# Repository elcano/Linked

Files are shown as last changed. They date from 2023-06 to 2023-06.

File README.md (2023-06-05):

# Linked
Physical coupling of vehicles

We evision modular electric automated vehicles that weigh less than the riders. Such vehicles are supported by other code in the Elcano repository. The Linked repository contains CAD files for mechanical parts that allow vehicles to couple into a road train that behaves as a single vehicle. The Linked repository will also contain software to enable vehicles to dock and undock.
Automated vehicles travelling in platoons reduce energy consumption and increase road capacity. The effects are better with a smaller gap between vehicles. However, a small gap results in a jerky ride as the vehicle constantly adjusts its following distance. Our solution is to shrink the gap to zero and drive bumper-to-bumper. Students at University of Washington, Bothell have developed a prototype couple that allows two vehicles to join together or separate while moving. The mechanism includes a spring to eliminate jerks.

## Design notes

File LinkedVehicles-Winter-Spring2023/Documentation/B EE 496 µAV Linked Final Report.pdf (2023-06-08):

## Final Report

## µAV Linked Vehicles

## 2022-2023 Academic School Year

## Sponsor: Tyler Folsom

## Devin Taing

## Rebecca Sasten

## Fletcher Kurita

## Li-Ling Plume

### Table of Contents

### 1. Overview

Introduction

This document serves as a technical user manual intended to provide an outline of the device that has been designed to fulfill the requirements as provided by Micro-AV. This device is to serve as a coupling mechanism which automatically links stationary or non-stationary mini-vehicles such as electric tricycles or vehicles similar to the ELF vehicle. It is important to note that the vehicle for which the system will be adapted to has not been finalized, and so instead of finalizing a design for a mode mounting between the vehicle and the linking system, a standardized coupling is to be set instead. Figure 1 provides the general appearance of the entire assembly.

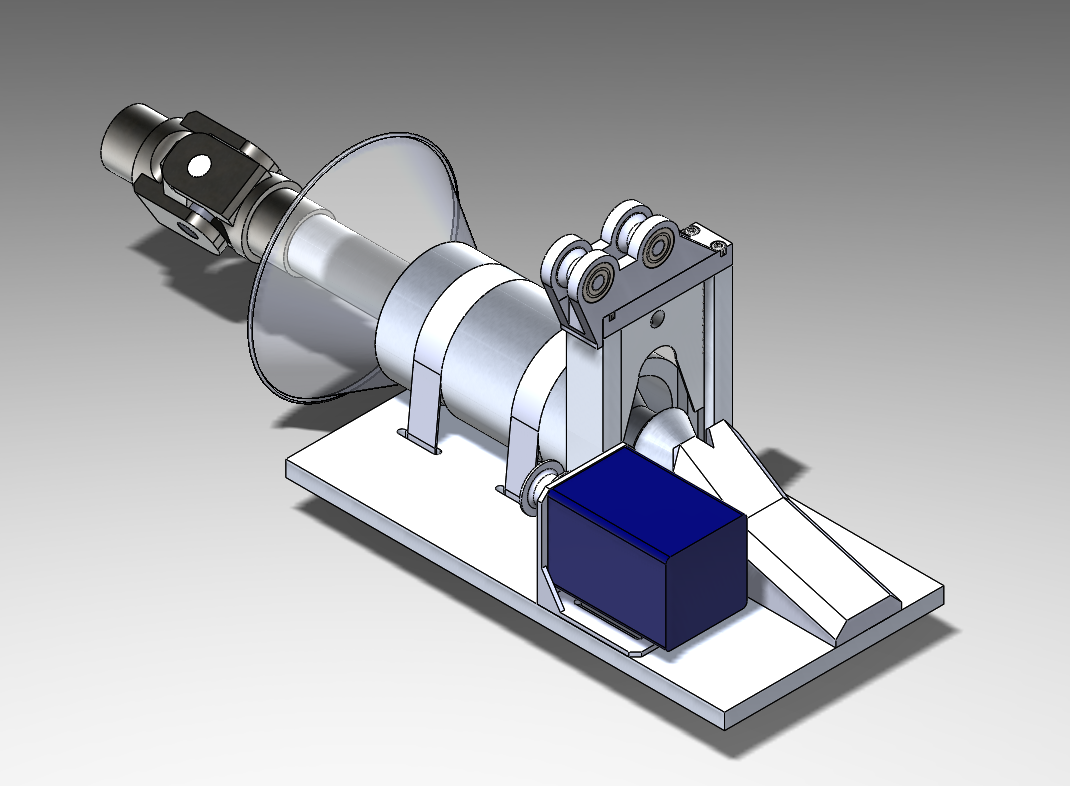
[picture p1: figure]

Figure 1. General Appearance of Assembly

Project Initial State

The system in its initial state was conceptual. The existing physical systems consisted of two separate trike systems that were not fully motorized with some electrical systems. As for the coupling system, due to the fact that the system was yet to be designed, there were no physical components or materials readily available on hand or to be ordered.

The project existed primarily as a set of requirements that needed to be fulfilled. The system was to be able to link two vehicles to one another by utilizing a bumper system without requiring direct human intervention when either coupling or decoupling. The system was to be mounted to be compatible with both ELF vehicles and electric trikes. Due to the fact that the trikes were already on hand, the system was to be designed according to the trikes. The requirements and constraints are to be further detailed below.

Constraints

The following system has been designed to meet the following specifications:

- Coupling is purely automatic
- Decoupling does not require human interaction
- All components within system are capable of withstanding forces due to collisions with a 5 mile per hour differential
- Supports vehicle weights of 40 lbs
*A lifetime of approximately 30,000 couples – untested

The processes in which these specifications have been designed to be tested for will be detailed in section 7.

Key Features and Functionality

There are four primary components that interact in the system, the male assembly, the female assembly, the locking mechanism assembly, and the dampening assembly.

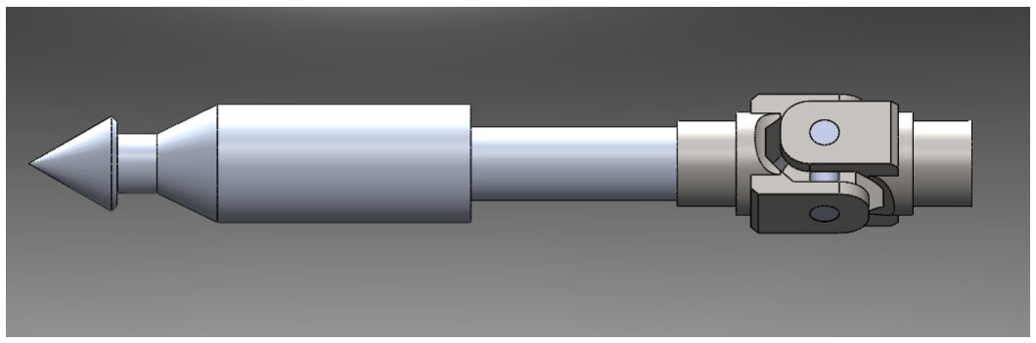
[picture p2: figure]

Figure 2. Male Assembly
The male assembly consists of a shaft which is connected to a universal joint. The end of the shaft is tapered to allow for a smoother coupling process when entering the female and locking mechanism assemblies. The universal joint allows for multiple degrees of freedom during the operation of the trike when it is coupled. The male assembly is to be mounted to the front of a vehicle.

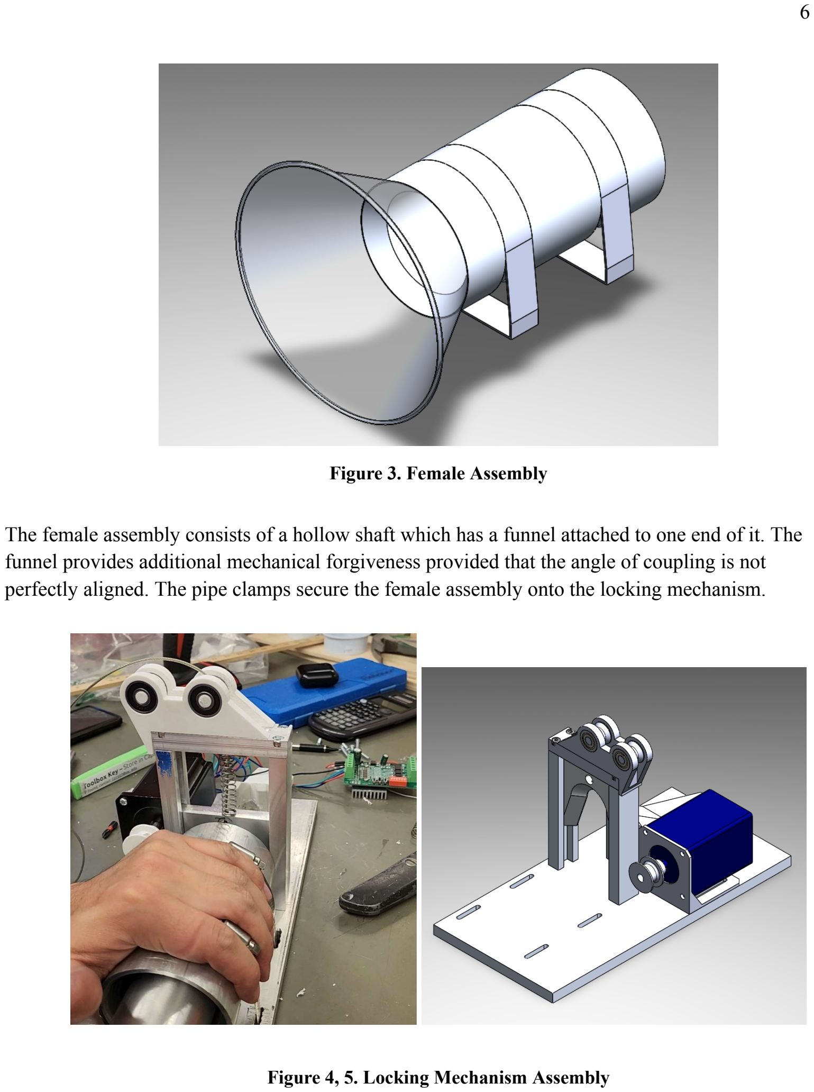
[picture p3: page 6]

Figure 3. Female Assembly

The female assembly consists of a hollow shaft which has a funnel attached to one end of it. The funnel provides additional mechanical forgiveness provided that the angle of coupling is not perfectly aligned. The pipe clamps secure the female assembly onto the locking mechanism.

Figure 4, 5. Locking Mechanism Assembly

The locking mechanism assembly consists of multiple mechanisms. The locking gate is the primary function that locks the male shaft into place after traveling through the female assembly. The face of the locking gate is chamfered such that it is concave facing the male assembly, allowing for it to be pushed easier. As the maximum diameter of the male head exceeds that of the gate, the male is automatically locked in once it passes through the gate. A rubber spring bumper will be mounted to the end of the base plate after the male shaft passes through the gate, which will prevent it from over-traveling.

To decouple, a stepper motor applies torque to a pulley and cable which pulls the locking gate up. Return springs apply a downward resistive force such that tension remains on the cable, preventing it from becoming unraveled, and pushes the locking gate down to resting position, where it is making contact with the base plate.

### 2. Parts List

### TOP LEVEL

ITEM NO | DESCRIPTION
1.0 | MALE ASSEMBLY
2.0 | FEMALE ASSEMBLY
3.0 | LOCKING MECHANISM ASSEMBLY
4.0 | DAMPING ASSEMBLY
5.0 | TEST ASSEMBLY

### 1. MALE ASSEMBLY

ITEM NO. | ITEM | DESCRIPTION
1.1 | MALE SHAFT | Universal Joint Assemblies (Standard Series): 1 1/4’’ x 1 1/4’’ I.D.(Inner Diameter), 1000 RPM, 800 Lbs, 5" Overall Length, 1/4’’ Keyway, 133020
1.2 | U-JOINT | Universal Joint Assemblies (Standard Series): 1 1/4’’ x 1 1/4’’ I.D.(Inner Diameter), 1000 RPM, 800 Lbs, 5" Overall Length, 1/4’’ Keyway, 133020
1.3 | MALE SHAFT SET SCREW | 3/8-16 x 1/2" Hex Head Screw Bolt, 10Pcs 18-8 (304) Stainless Steel, Fully Threaded, Plain Finish, by SG TZH

### 2. FEMALE ASSEMBLY

ITEM NO. | ITEM | DESCRIPTION
2.1 | FUNNEL | 24 FL oz Tin Funnel
2.2 | PIPE CLAMP | VIVOSUN Stainless Steel Air Ducting Clamps, 4/6/8/12 Inch Adjustable Hose Clamps with Worm Drive for Ducting, Heating, Cooling, Exhaust, and Ventilation (Pack of 2) (12 inch size)
2.3 | FEMALE SHAFT | Multipurpose 6061 Aluminum Round Tube, 3/8" Wall Thickness, 3" OD, 2ft length

### 3. LOCKING MECHANISM ASSEMBLY

ITEM NO. | ITEM | DESCRIPTION
3.1 | BASE PLATE | Multipurpose 6061 Aluminum, 7/16" Thick, 6" x 12"
3.2 | LOCKING GATE | Multipurpose 6061 Aluminum, 7/16" Thick, 6" x 12"
3.3 | RAIL GUIDE | Multipurpose 6061 Aluminum Sheets and Bars 1/2" Thick 1" Extruded 2ft Length
3.4 | RETURN SPRING | Corrosion-Resistant Precision Compression Springs 2" Long, 0.42" OD, 0.336" ID, 302 Stainless Steel
3.4* | RETURN SPRING (ALT) | Corrosion-Resistant Precision Compression Springs 2" Long, 0.42" OD, 0.31" ID, 302 Stainless Steel
3.5 | RUBBER SPRING ASSY | Ultra-High-Load Fastener-Mount Compression Spring, 1" Long
3.6 | ARDUINO UNO BOARD | Arduino Uno REV3

3.7 | MOTOR | STEPPERONLINE Nema 23 Stepper Motor 2.4Nm(339.79oz.in) 4.0A 8mm Shaft 57x57x82mm 4 Wires
3.8 | MOTOR MOUNT | weideer 2Pcs 57mm Stepper Motor Mounting Bracket Alloy Steel L-Shape Fixed Seat for NEMA23 Stepper Motor with Screws and Nuts K-029-57
3.9 | BRAIDED CABLE | 18-8 Stainless Steel Lanyard - Not for Lifting, Ball with Shank/Plain-End, 3/64" Rope Diameter, 24" Long, Nylon
3.10 | DRIVER BOARD | HiLetgo TB6560 3A CNC Router Single 1 Axis Controller Stepper Motor Driver Board
3.11 | PULLEY HOLDER | 3D PRINTED PLA PULLEY HOLDER
3.12 | PULLEY | 3D PRINTED PLA PULLEY
3.13 | SCREW | Zn-Plated Alloy Steel Socket Head Screw, 8-32 Thread, 3/4" Long

### 4. DAMPING ASSEMBLY

ITEM NO. | ITEM | DESCRIPTION
4.1 | AIR SHOCK | DNM Damping 3 System Mountain Bike Air Rear Shock Rebound/Lock Out/Air Pressure Adjustable AL 7005 Shark/AL 6061 Shock Body 165mm (6.5") x 35mm 190mm (7.48") x 50mm 200mm (7.87") x 55mm
4.2 | AIR SHOCK MOUNT | 3D PRINTED

### 5. TEST ASSEMBLY

ITEM NO. | ITEM | DESCRIPTION
5.1 | DOLLY | NA

Cost Estimate

ITEM NO. | ITEM | PRICE | QTY | NOTES | SOURCE
1.1 | MALE SHAFT | $ 45.64 | 1 | | Link (https://www.mcmaster.com/aluminum-shaft-stock/shape~rod-and-disc/diameter~2/appearance~matte/appearance~plain/material~aluminum/)
1.2 | U-JOINT | $ 66.70 | 1 | | Link (https://www.amazon.com/dp/B07DJ5LRYC?s=industrial&sp_csd=d2lkZ2V0TmFtZT1zcF9kZXRhaWw)
1.3 | MALE SHAFT SET SCREW | $ 8.13 | 1 | Purchased in Set of 10 | Link (https://www.amazon.com/Stainless-Threaded-Finish-SG-TZH/dp/B0B6BNVLQD?s=industrial)
2.1 | FUNNEL | $7.79 | 1 | | Link (https://www.mcmaster.com/products/funnels/metal-funnels-6/)
2.2 | PIPE CLAMP | $12.99 | 1 | | Link (https://www.amazon.com/STEELSOFT-Assortment-Stronger-Fasteners-Stainless/dp/B08Y6LSL3R)
2.3 | FEMALE SHAFT | $126.05 | 1 | | Link (https://www.mcmaster.com/products/shaft-stock/id~2-1-4/wall-thickness~3-4/wall-thickness~3-8/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)
3.1 | BASE PLATE | $31.17 | 1 | | Link (https://www.mcmaster.com/products/~/thickness~7-16/material~6061-aluminum/?s=aluminum+sheet+metal)
3.2 | BASEPLATE/LOCKING GATE | NA | 1 | Using same stock metal as Item 3.1 | Link (https://www.mcmaster.com/products/~/thickness~7-16/material~6061-aluminum/?s=aluminum+sheet+metal)
3.3 | RAIL GUIDE | $26.14 | 2 | | Link (https://www.mcmaster.com/products/bars/multipurpose-6061-aluminum-sheets-and-bars-7/width~1/thickness~1-2/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)
3.4 | RETURN SPRING | $7.33 | 1 | | Link (https://www.mcmaster.com/9002T434/)
3.4* | RETURN SPRING (ALT) | $8.14 | 1 | | Link (https://www.mcmaster.com/9002T438/)
3.5 | RUBBER SPRING | $11.43 | 1 | | Link (https://www.mcmaster.com/catalog/129/1505/9677K12)
3.6 | ARDUINO UNO BOARD | $29.95 | 1 | | Link (https://www.amazon.com/Arduino-A000066-ARDUINO-UNO-R3/dp/B008GRTSV6)
3.7 | MOTOR | $25.99 | 1 | | Link (https://www.amazon.com/STEPPERONLINE-Stepper-Motor-339-79oz-57x57x82mm/dp/B091C37FJ2?hvadid=532798192203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)
3.8 | MOTOR MOUNT | $10.99 | 1 | | Link (https://www.amazon.com/dp/B09374HZHF?s=hi&sp_csd=d2lkZ2V0TmFtZT1zcF9kZXRhaWxfdGhlbWF0aWM)
3.9 | BRAIDED CABLE | $3.07 | 1 | | Link (https://www.mcmaster.com/products/braided-wire/attachment-type~plain/length~24/flexibility~flexible/diameter~3-64/)
3.10 | DRIVER BOARD | $11.39 | 1 | | Link (https://www.amazon.com/HiLetgo-TB6560-Router-Controller-Stepper/dp/B00LPK02SY)
3.11 | PULLEY HOLDER | NA | NA | 3D PRINTED | NA
3.12 | PULLEY | NA | NA | 3D PRINTED | NA
3.13 | SCREWS | 8.03 | 1 | Purchased in Pack of 50 | Link (https://www.mcmaster.com/catalog/129/3498/90128A197)
4.1 | AIR SHOCK | $119.98 | 1 | | Link (https://www.amazon.com/DNM-Damping-Mountain-Pressure-Adjustable/dp/B00FLTZ2ZS/)
4.2 | AIR SHOCK MOUNT | NA | 1 | | Link (https://www.amazon.com/motorcycle-absorption-suspension-mounting-Eliminator/dp/B09WF424ZL)
| COST OF PARTS | $ 552.88
| COST OF MACHINING | $ 326.87
| TOTAL COST | $ 879.75

### 3. Machining Drawings and Documentation

Male Shaft

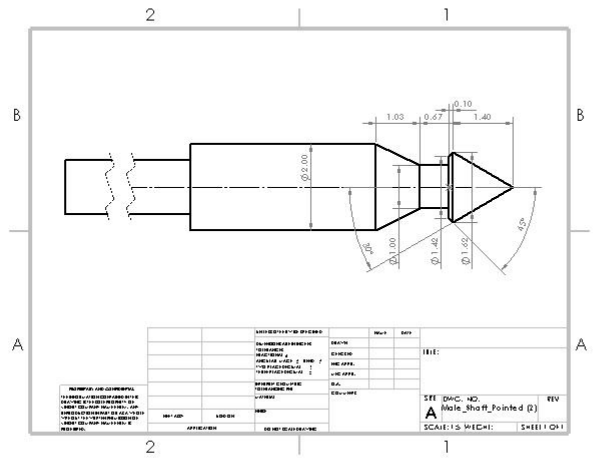
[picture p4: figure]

Figure 6. Male Shaft Machining Schematic

The male shaft was arguably the most complex machined item made in the entire assembly. The male shaft was made from Item No. 1.1. Item No. 1.1 was cut down the middle on the vertical band saw to create 2 roughly 12” long pieces. Each 12” piece of stock was loaded into the lathe with the 4 jaw independent chuck in addition to the live center mounted in the tail stock in order to ensure adequate contact before machining on the lathe. The first step of machining the male shaft was to cut the taper on the tip of the male shaft. This was done by setting the compound slide to the required angle and utilizing the left handed turning tool. After the taper was completed the interior shoulder and taper towards the base of the shaft were cut simultaneously with the same left handed turning tool. The dial gauge was utilized for this application to ensure accurate dimensions. The chamfer on the tip of the male shaft was completed also with the compound slide. A shoulder was turned down on the end of the shaft to fit into the universal joint. For weight savings the center of the shaft was core drilled with a large diameter drill bit roughly 5-6” into the shaft. If a longer drill bit was available, the shaft would have been drilled further to reduce weight even more. Weight can also be reduced in the future by bringing the interior diameter (fitting the universal joint) further up the shaft therefore extending that shoulder to reduce even more material.

Female Shaft

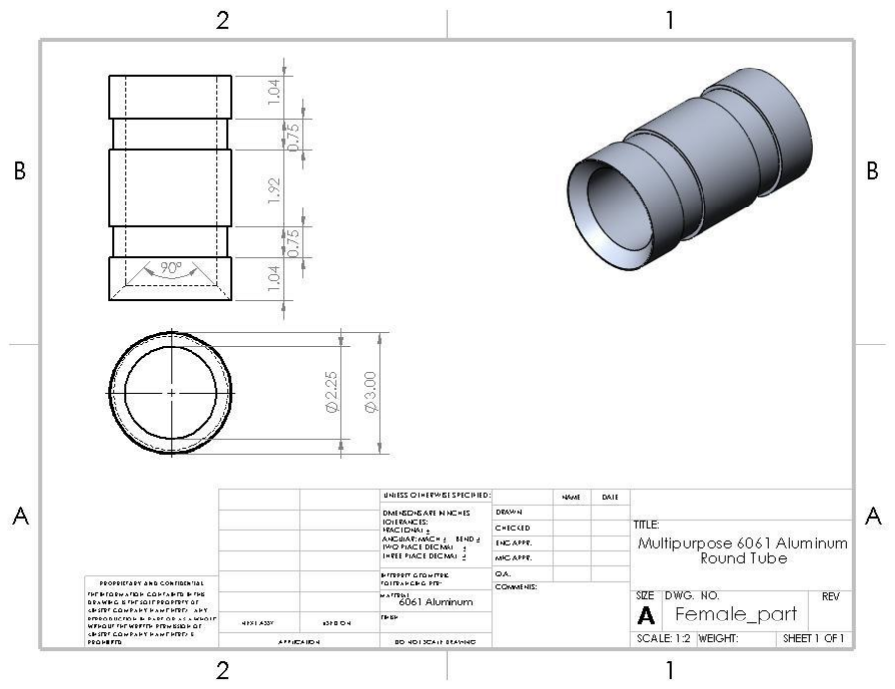
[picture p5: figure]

Figure 7. Female Shaft Machining Schematic

Female shaft was made from Item No. 2.3. Two (roughly) 5.5” lengths were cut from each end of the bar stock on the vertical bandsaw. After each length was cut to size the interior 45 degree chamfer was done with a right hand turning tool on the lathe. The two indented bands for the pipe clamps were also done with a right hand turning tool and pre-planned and measured according to the drawing above. These bands were not made exactly to spec as they can be within a very rough tolerance for our application. To reduce weight in the future the female shaft could be shorter and made from aluminum stock with thinner walls that will still accommodate the forces of the system.

Rails

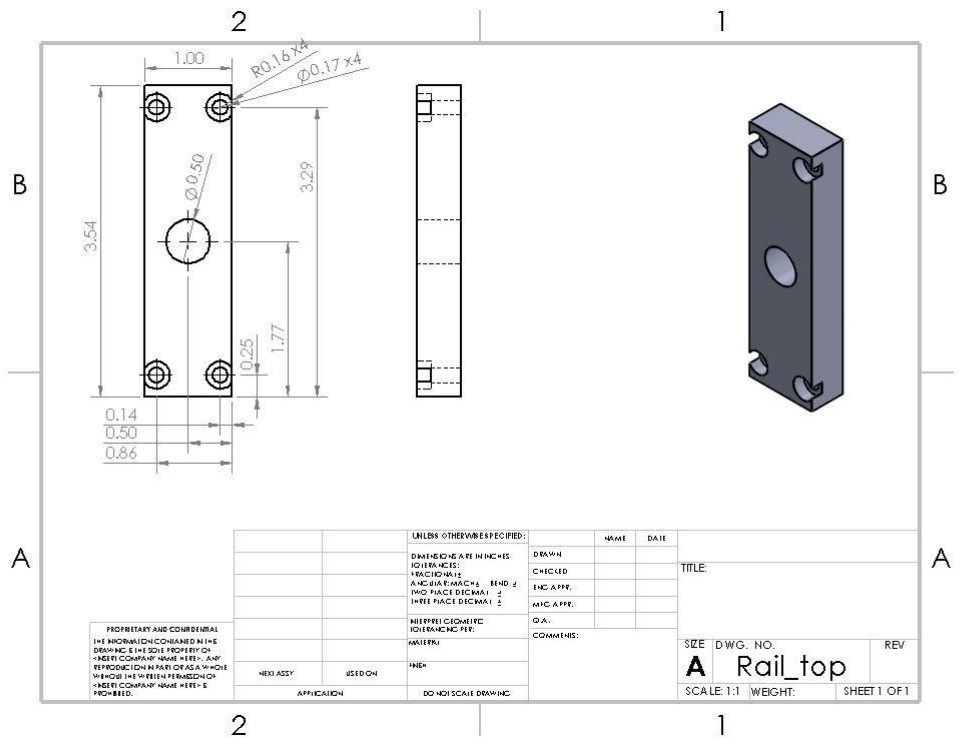
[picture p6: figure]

Figure 8. Rail Top Machining Schematic

The top portion of the rail was made of Item No. 3.3. The rail was cut to (roughly) 3.29” on the vertical band saw. After the rail was cut to size it was then scribed and center punched according to the dimensions listed above. The 5 holes were then center drilled and each hole was drilled to size as specified above. The 4 corner holes were counterbored with a larger drill bit size as the UWB shop does not have any counterboring bits.

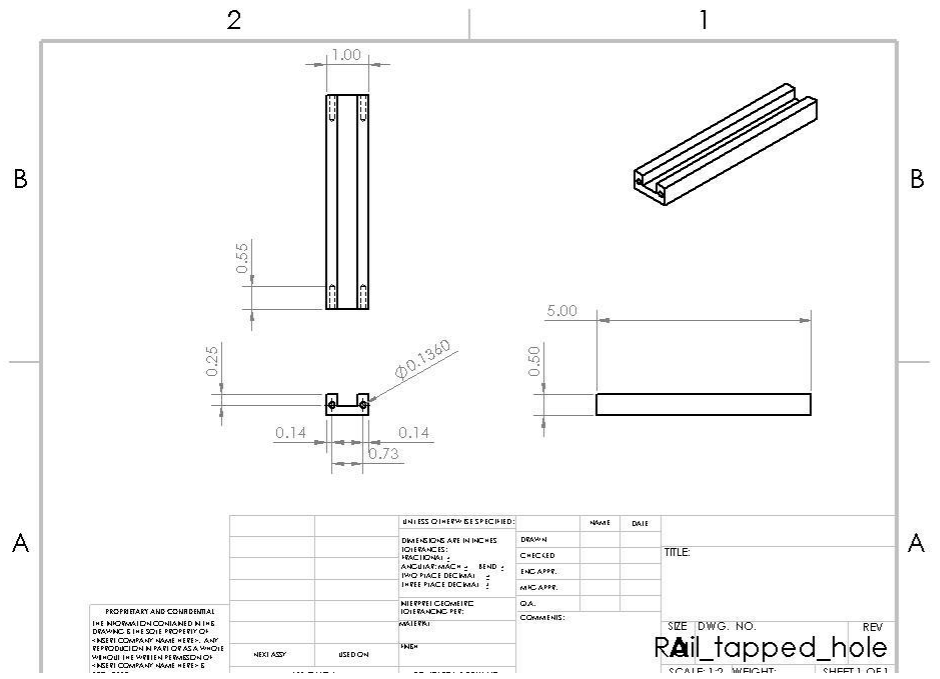
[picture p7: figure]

Figure 9. Rail Side Machining Schematic

The two side components of the rail are also made from Item No. 3.3. Two 5” pieces were cut from the stock with the vertical bandsaw with a rough 0.20” overhang to account for facing on the Manual Mill. After the pieces were cut roughly to size all 6 sides were then faced on the Manual Mill to ensure a smooth surface. After the pieces were faced they were individually channeled to create the interior channel to accommodate the locking gate. A ⅜” milling bit was used in accordance with the manual feed to take off roughly 20 thou of material at a time and create the channel. Once the channel was created it was then extended by a specified amount on each side of the pre-existing channel to create a total channel width of roughly half an inch.

Baseplate

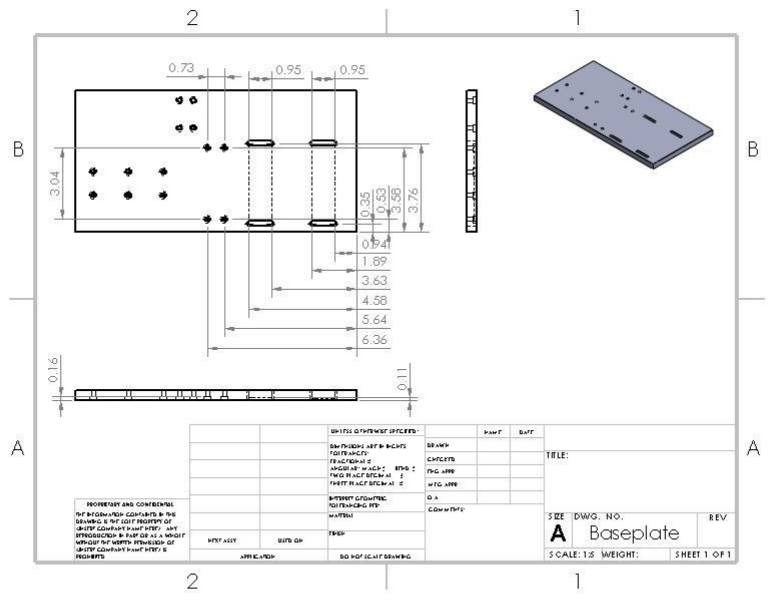
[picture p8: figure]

Figure 10. Base Plate Machining Schematic

The baseplate was made from Item No. 3.2. Two of the 7/16” edges were faced in order to create a perpendicular angle in order to accurately pre plan and dimension the holes on the base plate. All holes were center drilled and then drilled to size with the corresponding drill bit on the drill press. Some holes were counterbored with a larger drill bit size according to the drawing above. The slots for the pipe clamps were drilled out with a smaller drill bit and then were smoothed out with the use of a Dremel. In the future the baseplate can be modified to accommodate greater weight savings by cutting out parts of the plate not utilized by other components in the assembly. There will also be additional holes drilled into the baseplate in order to mount the assembly for testing.

Locking Gate

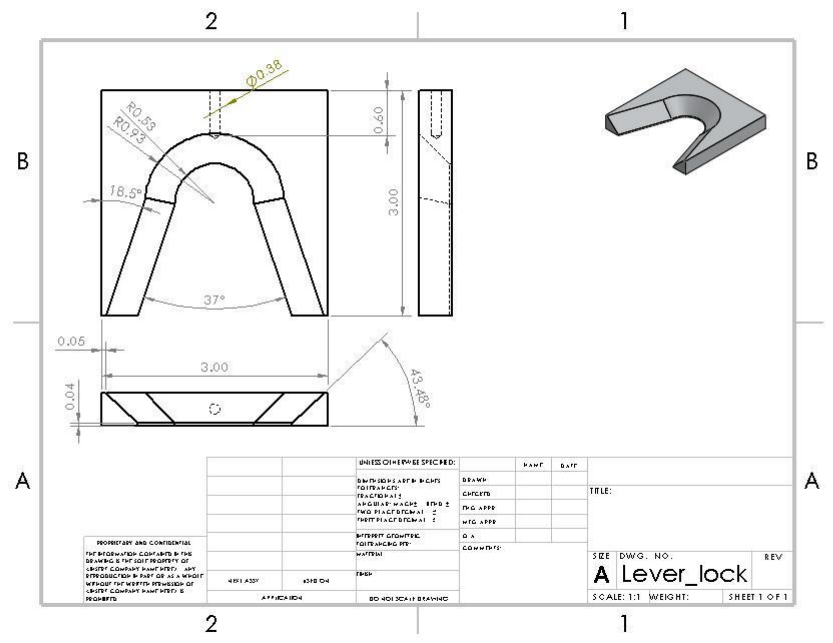
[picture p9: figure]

Figure 11. Locking Gate Machining Schematic

The locking gate was made from Item No. 3.2 and was cut to a 3.5”x3.5” square on the vertical band saw to allow room for cutting down to true size. This part needed to be within a tighter tolerance than the other machined piece such as the male and female shaft in order to properly interact with the machined rails. After the piece was cut to the 3.5” square, it was faced on all 6 sides on the manual mill and then loaded into the (Tormach 3 Axis) CNC. The CNC was utilized first to cut down the piece to an exact 3” square. Once the locking gate was cut to true size it was then loaded into the CNC again to have the interior portion removed according to the drawing above. This process was a bit of a trial and error as the G-CODE necessary for cutting the part had a few problems. The G-CODE was extracted through SolidWorks CAM after initializing the system according to the CNC specifications and toolcrib.

Additional Items

All additional items in the assembly were either 3D printed in house or purchased as is.

3D Printed:
- Pulley
- Dampening block
- Bearing Rail Mount for Cable Purchased:
- Universal Joint
- Universal Adjustable Pipe Clamps
- Stepper Motor
- Stepper Motor Mount
- Funnel

*The funnel was purchased and modified to fit the assembly. Modified and cut to size with metal shears.

Machining Time and Feasibility

Overall the machining of all components took roughly 30-40 work hours split between two people. There were many hardships associated with machining this project as the UWB machine shop was constantly in use and it was difficult to utilize the machines needed. There were also a limited number of hours available for shop use due to the requirement of supervision while running machinery.

If this project were to be outsourced to a machine shop it would take no more than half the time as a rough estimate. Outsourcing machining can cost anywhere between $40-150 per hour depending on the shop and what machines need to be utilized. This cost is not including the raw cost of the (stock) material itself which is roughly $300. On average I would estimate that outsourcing a second set to a machine shop to manufacture would be about $1500.

### 4. Electrical Schematics

Motor Wiring

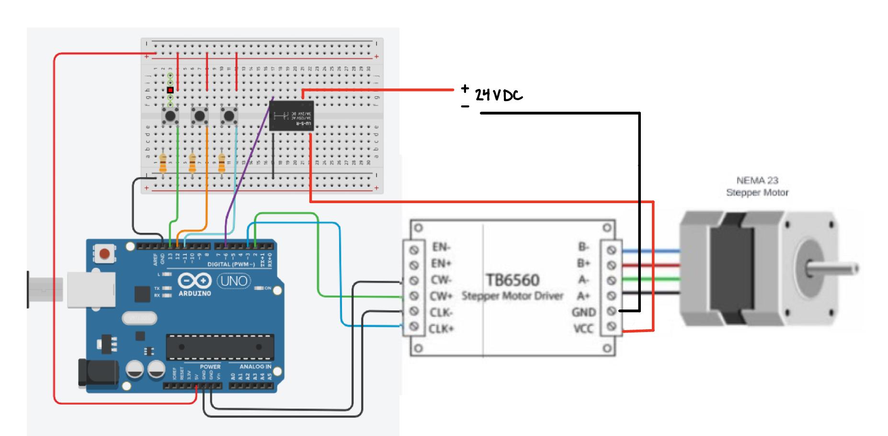
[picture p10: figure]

Figure 12. Motor Wiring Diagram

The CW+ connection of the motor driver is connected to pin 2 on the Arduino, which controls the direction of the motor. The CLK+ connection of the motor driver is connection to pin 3 on the Arduino, which controls the stepping. Additionally, there are three buttons, connected to pin 13, 12, and 11 of the Arduino through the breadboard. The button connected to pin 13 will cause the motor to raise the gate to decoupling height. The button connected to pin 12 will switch the relay and therefore cut power to the motor, dropping the gate. The button connected to pin 11 will single step the motor in the upward directions. The GND and VCC connections are to a 24V DC power supply through a relay controlled by the 5V signal from pin 6 on the Arduino.

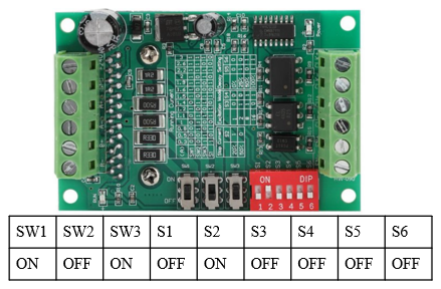
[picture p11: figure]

Figure 13. Motor Driver Switch Settings

The TB6560 is an analog motor driver board, which allows for control over the speed and stepping of the motor without making modifications to the code.. The interface for changing these parameters are the series of 9 switches on the bottom right corner of the board, as pictured above. The settings are shown in the figure above, and the switch configuration tables can be found in the Appendix section.

5

C

o

d

e

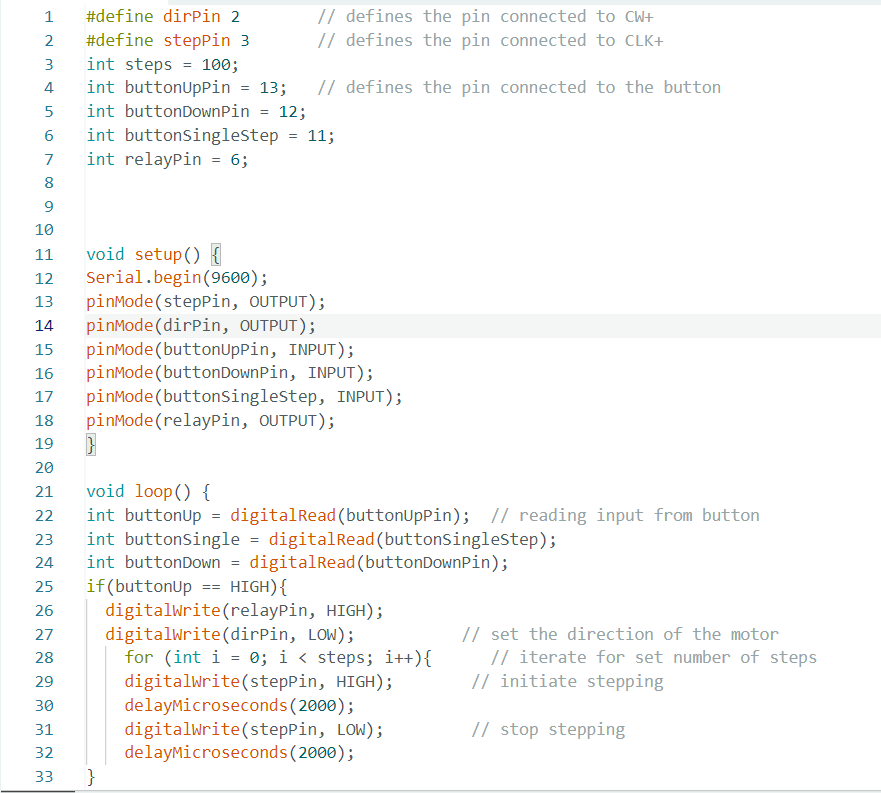
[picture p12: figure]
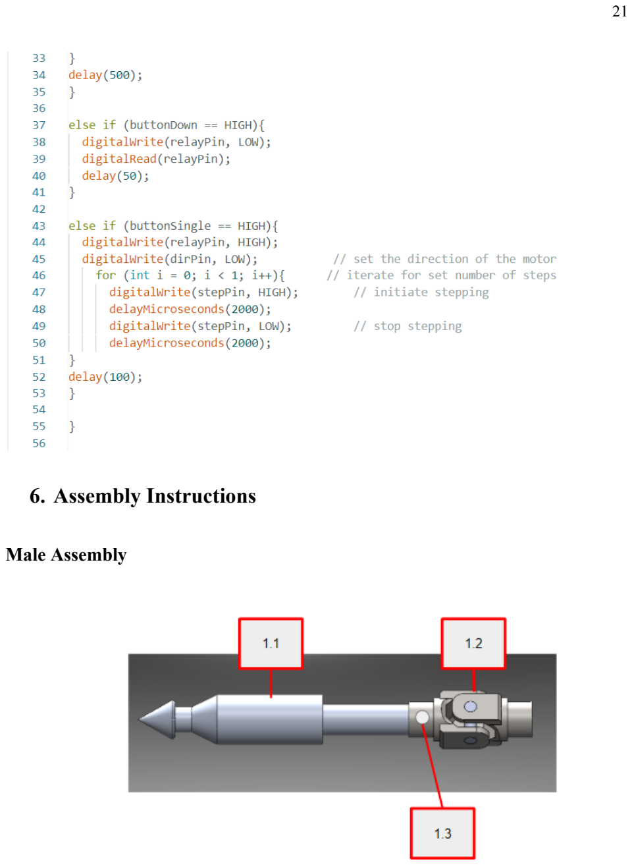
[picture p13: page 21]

### 6. Assembly Instructions

Male Assembly

Figure 14. Male Assembly
1. Using Item 1.3 (Male Shaft Set Screw), fix Item 1.2 (Universal Joint) onto Item 1.1 (Male Shaft)

Female Assembly

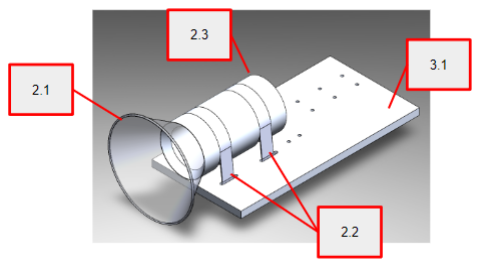
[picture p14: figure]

Figure 15. Female Assembly

1. Slide Item 2.1 (Funnel) over Item 2.3 (Female Shaft). Secure with metal zip ties.
2. Place the combined items 2.1 (Funnel) and 2.3 (Female Shaft) on Item 3.1 (Base Plate).
3. Route both counts of Item 2.2 (Pipe Clamp) through the four slots in Item 3.1 (Base Plate). Secure with screwdriver.

Damping Assembly

1. Construct Item 3.3 (Rail Guide), screwing them onto Item 3.1 (Base Plate) into the tapped holes as shown below using Item 3.13 (Screws).

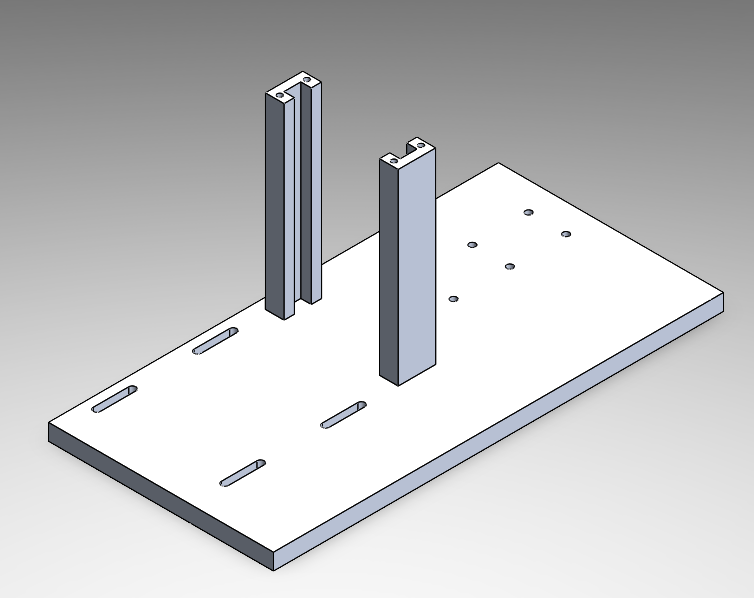
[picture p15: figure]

2. Place Item 3.2 (Locking Gate) into rails created by Item 3.3 (Rail Guide).

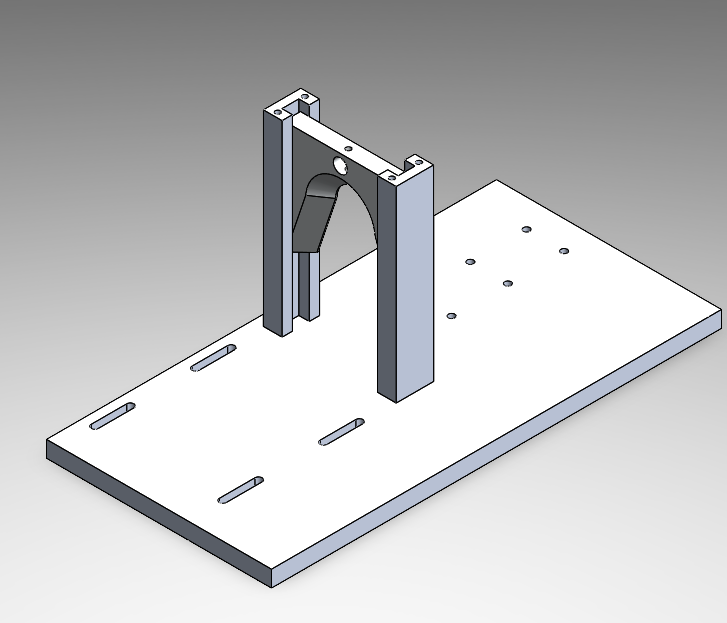
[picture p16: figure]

3. Route Item 3.9 (Braided Cable) through the slot in Item 3.2 (Locking Gate), then through Item 3.4 (Return Spring).
4. Install the top bar of Item 3.3 (Rail Guide) on top of the first two rail support structures. Screw in to secure with Item 3.13 (Screws). Secure Item 3.11 (Pulley Holder) on top of the top bar.

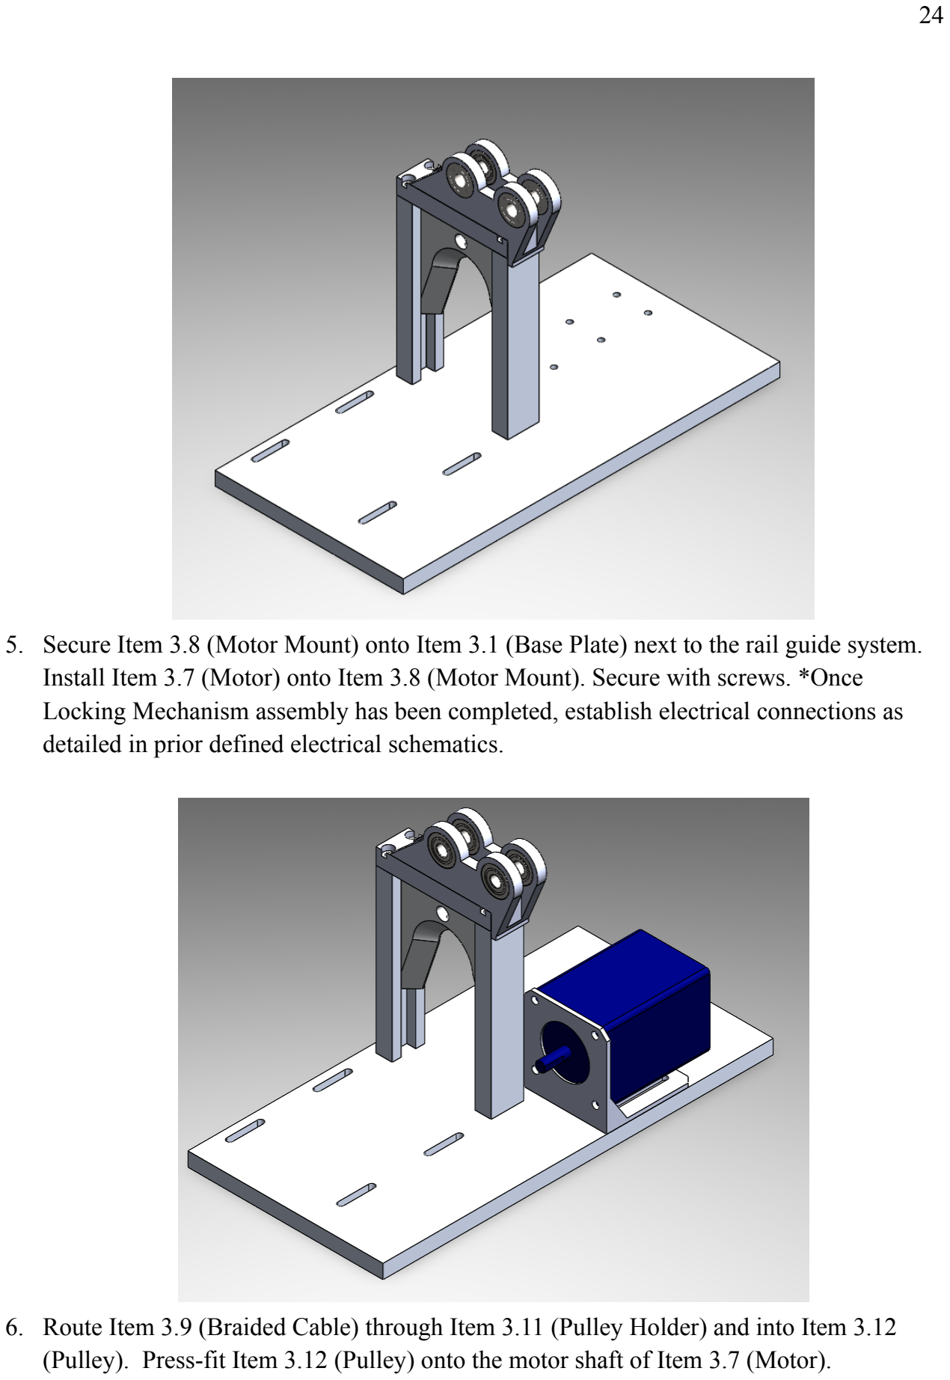
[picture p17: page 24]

5. Secure Item 3.8 (Motor Mount) onto Item 3.1 (Base Plate) next to the rail guide system. Install Item 3.7 (Motor) onto Item 3.8 (Motor Mount). Secure with screws. *Once Locking Mechanism assembly has been completed, establish electrical connections as detailed in prior defined electrical schematics.
6. Route Item 3.9 (Braided Cable) through Item 3.11 (Pulley Holder) and into Item 3.12 (Pulley). Press-fit Item 3.12 (Pulley) onto the motor shaft of Item 3.7 (Motor).

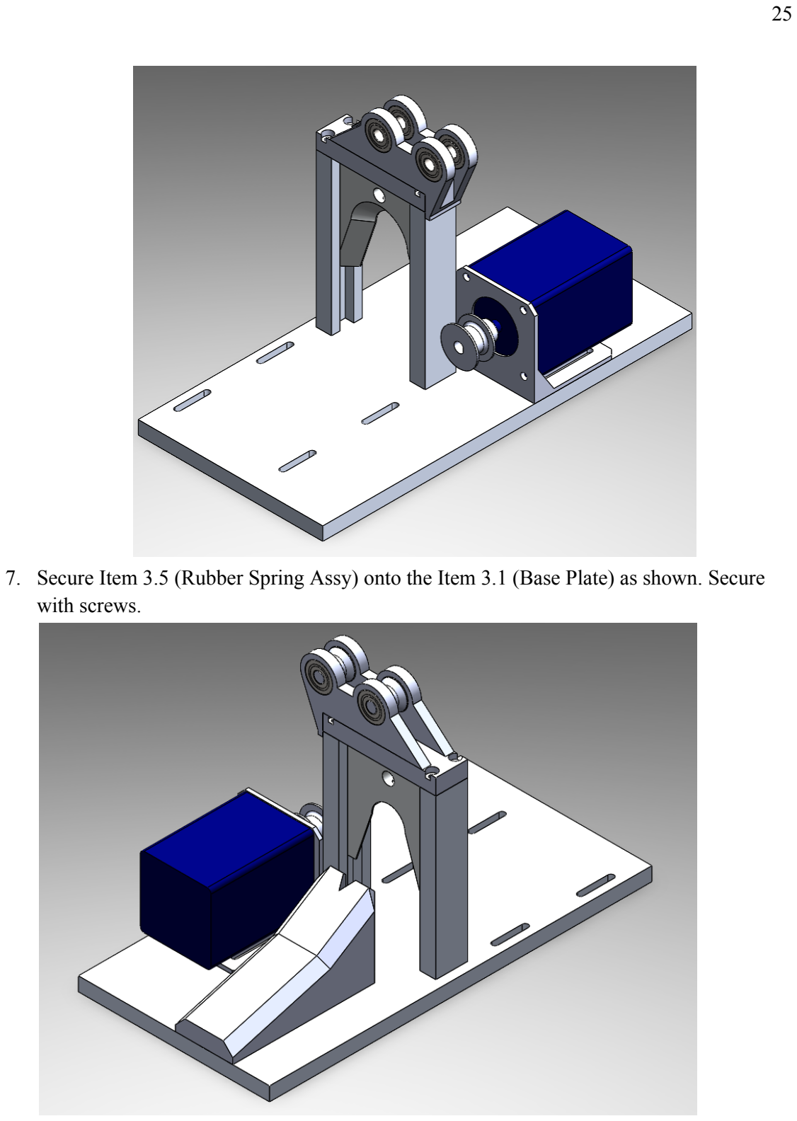
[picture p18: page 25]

7. Secure Item 3.5 (Rubber Spring Assy) onto the Item 3.1 (Base Plate) as shown. Secure with screws.

### 7. Testing & Verification

Procedures

In order to verify that the above design and process yields a system which meets specified requirements, a test procedure was drafted. There are three main functions which the system must satisfy, yielding three tests, which verify that
1. The system couples when the respective male and female assemblies collide at the specified speed differential (Coupling)
2. The system can allow for decoupling between male and female assemblies when programmed to do so (Decoupling)
3. The system allows for continuous linking between vehicles while traveling (Linking)

Test 1 – Coupling
1. Mount the respective male and female assemblies onto the test dollies. Allow a minimum of 10 feet between the dollies.
2. Leaving the dolly with the female assembly mounted stationary, push the dolly with the male assembly mounted towards the female assembly, aligning a path of collision.
3. Verify that the male shaft goes through the female assembly and pushes up the locking gate and passes through it, allowing the gate to close down on the shaft.

Test 2 – Decoupling
1. Mount the respective male and female assemblies onto the test dollies.
2. Couple the male and female assemblies by pushing the dollies towards each other.
3. Verify that power is being supplied to both the Arduino (5V) and the stepper motor (24V-36V).
4. Operate the switch button to verify that the motor
a. moves in the correct direction b. exerts the requisite torque to lift the locking gate while the system is coupled
c. exerts the requisite holding torque to maintain the gate at a height which allows the male shaft to decouple
d. releases the held torque to allow the locking gate to clamp down after a sufficient amount of time has elapsed.

Test 3 – Linking
1. Mount the respective male and female assemblies onto the test dollies.
2. Tie a rope around the dolly with the female assembly mounted.
3. Pull the dolly through various terrain conditions and verify that the coupler does not degrade in any fashion.

Test Reports

Since the tests performed were visual, there is no raw data and therefore a video is provided in the QR code below to show the current working state of the system. The video shows the coupling and decoupling test is demonstrated.

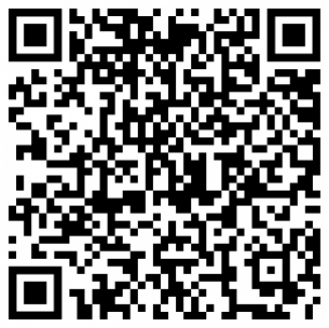
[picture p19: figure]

1. During coupling, the system performed as expected, with a reasonable amount of force required to lift the gate and secure the male shaft. This test was performed stationary and in alignment, as shown, and served to prove the success of the locking mechanism itself.
2. During decoupling, the motor was able to pull the gate up and hold it high enough for the male shaft to fully retreat and the return springs forced the gate back to the “ready” position. The test was deemed successful, however there may be room for improvement. A few observations during this test were that the springs were not strongly secured to the assembly relative to the amount of energy they stored, and the motor did not move smoothly or return to the exact same “ready” position each time. This caused some failed decoupling attempts, but these cases lessened as the motor code and assembly were tuned during the testing phase.

### 8. Future Work and Recommendations

To Be Completed:

I. Electrical Connection
A. Quick connect system near connection between male and female counterparts
B. All in one system (all on the same baseplate)
C. Acts as an interface for power and information to be shared between trikes

II. Integrated Shock/Dampening System
A. Male shaft machined in a way to make it “telescope” so dampening system can
| operate inside the shaft and be contained
B. Secondary/additional mounting for the dampening system in between the system
| and trikes consisting of an adjustable air shock to accommodate different weights/loads on the trikes
C. Upgrade the rubber hardstop (air shock, oil shock, spring)
1. Change the spring factor for coupling comfort based on
| cargo/passengers/etc.
D. Upgrade/improve the rubber hardstop’s mount to the baseboard
1. Make the position variable in the x,y,z
2. Upgrade material from PLA to more durable material that can sustain
| constant cyclic loading
III. | Mounting Currently the system is mounted to testing dollies for the sake of the current project scope. A concise mounting assembly will need to be manufactured and installed onto the trikes in order to incorporate the system into the Micro-AV physically linked vehicles.
| Both the male and female counterparts can be mounted to either the front or back of the trikes. It is important to note that mounting the male shaft to the front of the trike may pose some safety concerns. As a recommendation, It would also be easier to mount the female assembly to the back of the trikes given the current mounting surfaces, such as the rear bike rack frame. New mounting surfaces may also need to be manufactured for the trikes if the current mounting surfaces are not strong enough to accommodate the loads of the system. These mounting surfaces would need to be securely welded or bolted onto the chassis of the trikes. The mounting of the system will largely depend on further testing done once the trikes are fully operational.

IV. Improved Machining/Weight Reduction
A. Baseplate
1. Consider another material (wood or composites)
| *would recommend altering materials of other components before the baseplate due to it being the primary support structure and taking the majority of the load of the system*
2. Chamfer all edges for safety and usability
3. Improve design to reduce the overall unutilized sections
a) Run (SolidWorks) simulations to see where the baseplate is
| holding the most load/stress and shave the rest down
b) Trim with mill and bandsaw
4. Add small depressions/channels to the baseplate (utilizing the manual
| mill) that match up with the ribbed bands on the female part to keep it from sliding within the assembly
B. Rails
1. Run more testing for lifetime fatigue due to impacts because the rails take
| the majority of the impact and dynamic loading during coupling
2. If yielding or shear starts to develop increase the thickness to
| accommodate a third 8-32 screw or 2 larger screws
3. Make sure that both walls of the rail channel are down milled at a slow
| feed speed to get the smoothest finish (resulting in the lowest coefficient of friction)
C. Lever Lock
1. Run tests or simulations to find the best angle of the leverlock sweep
2. 7/16” flat aluminum stock is inexpensive, it is not difficult to manufacture
| multiple different iterations of the Lever Lock using the CNC machine
3. Potentially reduce the height of the lever lock to reduce the height of the
| rails (make the overall assembly shorter in the Z axis)
4. Change the lever lock material to one with a higher hardness (6061
| Aluminum is too soft for the male shaft to repeatedly hit long term, experience failure due to similar metals consistently colliding with another)
D. Top Connecting Rail
1. Reduce overall thickness (stresses are not high at the top of the rail
| assembly)
2. Clean up or redo the current one (done with minimal time and can be
| improved)
E. Female Shaft
1. Improve method of mounting to base plate (noted above)
2. Reduce thickness (and diameter) of tube stock for weight savings

3. Material change
F. Male Shaft
1. Reduce weight by coring the shaft or turn the outside of the shaft (from the second slope back) down to a smaller diameter and make a 3D printed sleeve that would save weight
2. Test different tip shapes for optimal coupling comfort
3. Test different tip shapes for optimal lever lock travel distance and engagement
4. Reduce overall length
G. Pulley System
1. Motor
a) Reduced motor size if friction and loads allow
b) Change to a geared setup for easier adjustments and increased engagement (complicated)
c) Print/manufacture housing to protect the current electronics and motor (motor and breadboard/wires exposed in current prototype)
d) Create a feedback loop to maintain set top and bottom positions
e) Remove the button press required to reset to the motor after decoupling (either have a sensor or a set time control)
2. Pulley
a) Manufacture out of metal to withstand long term stress (optional depending on further testing and results)
b) Change the radius if higher torque is required in the system
3. Pulley mount assembly
a) Reprint so skateboard bearings fit securely with a tighter tolerance
b) Reduce size (simulations needed for stresses to determine size)
c) Change material from PLA (PLA is not corrosion or weather resistant to long term exposure). Recommend Nylon X, PETG, or ABS.
4. Return springs
a) Attach to rails more securely
V. Second Set
A second set of both a male and female counterpart will need to be machined in order to allow for interchangeable coupling between two trikes. This second set will allow for each trike to have a corresponding set to be able to couple front to back and back to front. This is necessary for further implementation and testing of the physical platooning ideal that Micro-AV proposes for future use.
This second set can either be manufactured in house at UWB or it can be outsourced to a machine shop. Manufacturing in house would be more cost effective however it would be much more time consuming and results would not be up to par with those of outsourcing to a shop.

VI. Recommendations for Future Capstone Groups
As the current system and assembly is a rough prototype it would be beneficial for future groups to use this system as a starting point for future additions and improvements. As listed above, the system can be further modified through machining for weight reduction and increased efficiency. Given that the materials ordered to manufacture the system in house are inexpensive, it would be advantageous for future teams to experiment with creating their own male and female counterparts and the corresponding geometry. With continued prototyping the system will become increasingly more efficient.

One recommendation for future teams will be to further explore a solution that can accommodate yaw and pitch forces in the trikes when physically coupled. The current solution involves utilizing a universal joint connected to the male shaft to accommodate these forces. However, it is not feasible for use in transit as the universal joint does not have tight enough tolerances within the bearings and internal assembly to be able to support the weight of the male shaft when not connected to the rest of the system.

Overall, the main focus in future teams will revolve more heavily around the electrical side of the project as this year’s scope was focused mostly on the mechanical components. There will be mechanical changes that can be implemented and made as the electrical system and connections are further developed between the trikes and the assembly.

### 9. Appendix

References

[1] Shenzen Global Technology Co., LTD (Shenzen City, China). TB6560. Accessed: April 24, 2023. [Online]. Available: https://www.makerguides.com/wp-content/uploads/2019/08/TB6560-Manual.pdf
[2] “TB6560 Stepper Motor Driver with Arduino Tutorial.” MakerGuides. https://www.makerguides.com/tb6560-stepper-motor-driver-arduino-tutorial/ (retrieved April 24, 2023).

Additional Tables

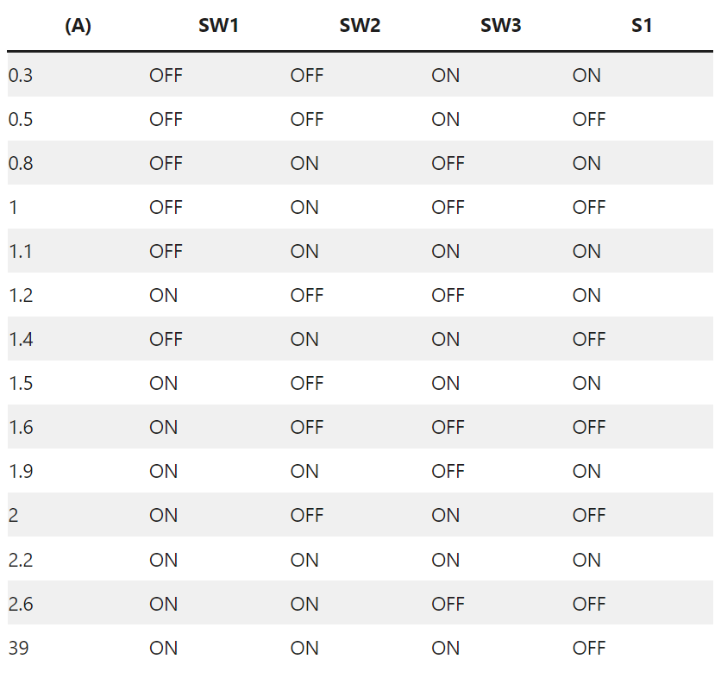
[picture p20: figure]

Figure A1. Current Table

The current going through the motor is adjusted by setting the switches SW1, SW2, SW3, and S1 on or off.

Figure A2. Stop Current Table

The stop current is the current used to hold the motor at a stopped position, and can be adjusted by turning S2 on or off. A higher stop current value will result in increased holding torque.

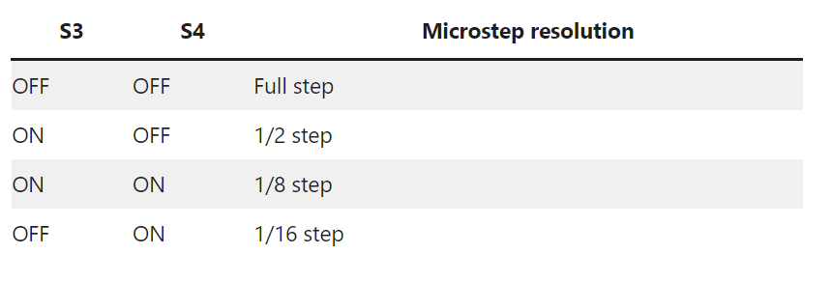
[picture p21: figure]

Figure A3. Microstep Table

The microstepping can be adjusted by turning switches S3 and S4 on or off. A smaller microstep resolution will result in smoother movement.

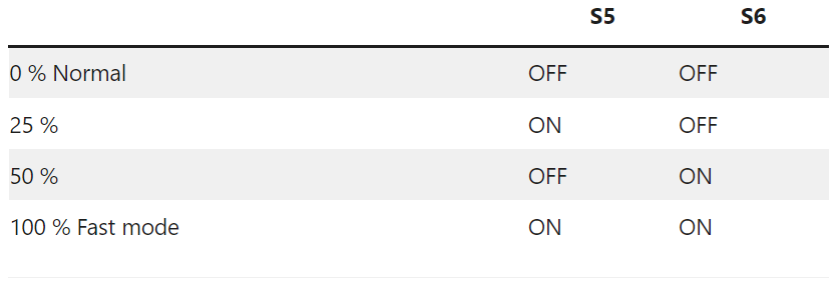
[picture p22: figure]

Figure A4. Decay Setting Table

The decay setting determines how the driver chip deals with back EMF from the motor, and can be adjusted using switches S5 and S6.

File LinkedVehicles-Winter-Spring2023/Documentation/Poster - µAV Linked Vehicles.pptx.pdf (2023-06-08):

# µAV - Linked Vehicles

# Devin Taing Li-Ling Plume Fletcher Kurita Rebecca Sasten

## BACKGROUND & INTRODUCTION

## dpt7@uw.edu lplume@uw.edu fletchku@uw.edu rsasten@uw.edu

## TEST METHODS & RESULTS

## CONCLUSION/FUTURE WORK

## KEY FEATURES

µAV is a company which aims to address vehicular inefficiencies in transportation. Emulating truck platooning to reduce fuel expenditure, µAV seeks to physically link small electric vehicles together instead. As these smaller vehicles can move independently, this proposes a modular bus system where vehicles can link and unlink as needed during transportation. To accomplish this, the design of a coupling system is required.

The system:
- is to couple automatically
- remains coupled until instructed otherwise
- does not require human intervention to decouple
- withstands collision forces with a 5 mph differential
- supports weights of 200 lbs
- approximately 30,000 couples

## REQUIREMENTS & CONSTRAINTS

Design an electromechanical system to allow coupling and uncoupling of small vehicles given requirements and constraints as defined below.

Potential Modular Bus Design OBJECTIVES

The designed and manufactured solution meets the expectations of the previously listed requirements and constraints.
Future work of the system includes:
- Mount system to trikes (photo of trike shown below)
- Electrical connection between male and female coupler for inter trike data transfer
- Mechanism to allow additional degrees of freedom
- Integrate additional shock dampening system for increased user comfort during coupling
- Machine second set of couplers
- Further weight reductions

Pulley System

Male shaft

Female part

Lever lock rails

Baseplate
Hardstop

Motor

Lever lock

Pulley system: Uses a 50 lb braided cable to lift the lever lock using the motor Lever lock: Specialized CNC part that locks the male shaft into place
Motor: Geared stepper motor to lift the lever lock during decoupling
Hardstop: Remaining momentum of the system is absorbed into the hardstop Baseplate: Main mounting surface for the system
Lever lock rails: Precision milled aluminum designed to hold the lever lock Female part: Aluminum tube stock designed to take the initial forces of coupling Male shaft: Precision turned aluminum that is the primary locking element
1 2

3

(1) Lever lock in the locked position ready for coupling
(2) Male shaft forces lever up
(3) Springs slam lever lock down to complete coupling
Uncoupling: Steps 3-1 aided by the stepper motor to lift the lever lock
SPONSOR: TYLER FOLSOM | SPECIAL THANKS TO: BILL ANDERSON, JACOB ROTH, JONG YOON

Images Courtesy of µAV

Scanning the QR code will lead to a short video demo. This video demonstrates that the system is able to:
a) couple automatically upon collision to two vehicles
b) disengage the locking mechanism and allow the vehicles to uncouple

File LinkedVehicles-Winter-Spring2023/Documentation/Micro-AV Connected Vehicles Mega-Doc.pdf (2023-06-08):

## Mechanical Engineering Capstone Project

## µ-AV Connected/Linked Vehicles

## Final Mega Document BME 494, 495, 496

## Rebecca Sasten, Devin Taing, Li-Ling Plume, Fletcher Kurita

## Advisor: Dr. Tyler Folsom

## Mentor: Dr. Jong Yoon

## Sponsor: Dr. Tyler Folsom

## University of Washington Bothell

µAV-Linked Page 2

Table of Contents
Table of Contents | 2
A. Design Strategy | 5
A.1.1 Design Strategy – User Insights and Research, Consumer Journey Map | 5
Empathy Map | 5
Customer Journey Map | 6
A.1.2 Design Strategy – User Insights and Research, Stakeholder Framing. | 8
Stakeholders Map/Matrix of Power | 8
A.1.3 Design Strategy – User Insights and Research, User Scenarios and Personas. | 9
A.1.4 Design Strategy – User Insights and Research, User Insight Report | 12

A.2.1. Design Strategy – Problem Understanding and Framing, Product Assumptions
Outline | 13
Partial Needs Statement 1 | 14
Partial Needs Statement 2 | 14
Partial Needs Statement 3 | 15
A.2.2. Design Strategy--Functionality (tasks and associated outcomes) | 16
A.2.3. Design Strategy--High-level Constraints on the Usability of the Product | 16
A.2.4. Design Strategy--Final Needs Statement and User Outcomes | 17
A.2.5. Design Strategy--Hypothesis Statement | 18
A.2.6 Design Strategy--Possible Inventions and Business Model | 18
Systems Level Sketch Invention 1 | 19
Platooning enabled by wireless information transfer which can be used to inform vehicles to control distance between one another. Utilizing WiFi or other forms of wireless communication between vehicles, signals containing information vital to road operation would be collected using proximity sensors, GPS, lidar, or other similar mechanisms. This information would be transmitted between all vehicles within a specific range, allowing their
driving to be informed and synchronized to the point of platooning. | 20
Systems Level Sketch Invention 2 | 20
Systems Level Sketch Invention 3 | 21
Lean Canvas | 22
A.2.6.1 Design Strategy--Final Invention | 22
A.2.7 Design Strategy – Product Planning Roadmap | 23
Product Roadmap | 24
Product Development Timeline | 25

B. Experience Design | 26
B.1 Experience Design – Human Interface Design, User Workflow | 26
User Experience Flow Diagram | 26
B.2 Experience Design – Human Interface Design, Environmental analysis | 27
B.3 Experience Design – Human Interface Design, Cultural factors mapping | 27

B.4 Experience Design – Human Interface Design, Information Architecture and Hierarchy 29

B.5 Experience Design – Human Interface Design, Analog Interface Design | 30
B.7 Experience Design – Human Interface Design, Best Use Practices Report | 31
System Maintenance Plan | 32

B.8 Experience Design – Human Interface Design, the Summary Document, in essence a
Usability Requirements Documentation. | 32
C. Requirement Documentation | 34
C.1.1 Design Decisions and Rationale | 34
Female Counterpart | 34
Male Counterpart | 35
C.1.2 Tier 1 Schematics (block diagram) | 36
Level 1 Roadmap of Major Elements | 36
C.1.3 Tier 2 Schematics for each element (block diagram) | 37
Level 2 Roadmap of Individual Pieces within Elements | 37
Shaft (male part) | 38
Universal Joint (male part) | 38
Spring/Damper (male part) | 38
Receiver (female part) | 39
Lever Locking Mechanism (female part) | 39
Electrical Connection | 40
C.1.4 Tier 3 Schematics (concrete connections between blocks) | 40
C.2 Estimation of cost of goods | 41
Cost of Goods Chart | 42
C.3 Schedule | 43
Technical GANTT Chart | 43
Documentation GANTT Chart | 44

Technical Tasks & Deadlines | 44
Documentation Tasks & Deadlines | 45
D. Concept Development [Demonstrating the solution] | 46
D.1 Concept Development – Technology mapping, risk analysis and feasibility plan | 46
Risk & Resources Component-Level Breakdown | 46
Feasibility Timeline | 49
D.2 Design Strategy – Technology mapping, Component Technology Research | 50

D.2.1 Concept Development, Concept Risk Identification & Mitigation - EE/Circuit Models 50
Locking Mechanism | 50

D2.2 Concept Development, Concept Risk Identification & Mitigation - Mechanical Models 51
Damper Test | 51

D.2.3 Concept Development, Concept Risk Identification & Mitigation - Firmware and Software
Models | 52

D.2.4 Concept Development, Concept Risk Identification & Mitigation - Human Interaction
Models | 52

D.2.5 Concept Development, Concept Risk Identification & Mitigation - System interface
modeling, testing and risk analysis | 52
References: | 54

A. Design Strategy
A.1.1 Design Strategy – User Insights and Research, Consumer Journey Map
Our direct customer is the company Micro-AV. We are tasked with developing a coupling system for two vehicles in order to show a proof of concept. With this proof of concept, Micro-AV will be closer to the goal of platooning multiple vehicles for various purposes. This long term goal of platooning vehicles has been described in depth below along with other potential considerations in order to show the importance of developing this product.

Empathy Map
| Customer 1 | Customer 2 | Customer 3
Description | Bike share companies (like Lime) | Delivery companies (like Amazon, Uber Eats, etc.) | Personal use
Job | Provide affordable and reliable transportation. | Provide efficient and affordable small deliveries. | Buy e-trikes directly from Micro-AV.
Pains | Initial cost of switching to autonomous e-trikes, maintenance. | Initial costs of adding autonomous e-trikes to the delivery fleet, maintenance. | Initial cost of buying the e-trike, small cargo space, maintenance.
Gains | Increased usage since e-trikes can redistribute themselves to high-demand locations, less energy cost with platooning of e-trikes, include customers who can’t ride bikes or scooters safely. | Energy cost savings of not operating large vehicles for small deliveries, less employees to pay, quicker turnaround times since modules can return for reloading before the entire route is complete. | Reduce individual carbon footprint, save money by not buying a large personal vehicle and paying for fuel/insurance, a convenient option for auto-drive.

Here, the Consumer Empathy Map outlines three types of customers who may use the Micro-AV Millipod. There are 3 types of customers (bike share companies, delivery companies, and personal use). The customers are people and companies who will be directly purchasing vehicles or services from Micro-AV, and their pains are primarily how their funds will be used, and the gains are how they will benefit from their purchase. Some of these customers, such as bike share companies and delivery companies will also have users that will pay to use these products. For example, the customers of the bike share company will be using the Millipod trikes to commute within the city, and the delivery company customers will be indirectly using the trikes to schedule their deliveries.

Customer Journey Map
The Customer Journey Map shows a potential process of a single customer deciding whether a Micro-AV Millipod is a worthwhile investment. This journey map follows a customer named Vlad, who is an analytical thinker and puts a lot of thought into his purchase decisions. His journey starts with seeing a couple ads for the Micro-AV Millipod trikes on multiple platforms. These commercials spark his interest, as he is looking for affordable, reliable, and accessible transportation through the city of Seattle, so he decides to explore the options of using a Micro-AV Millipod and compare the pros and cons with his needs. He spends considerable time exploring and comparing different options of using this mode of transportation, as well as doing cost analysis and reading customer reviews. After he is satisfied with the information he finds on the internet, he decides to test the vehicles for 2 weeks and take notes on his experience. Eventually he decides to purchase a Micro-AV Millipod trike directly from Micro-AV and use it as his every day mode of transportation throughout the city. He is satisfied with his purchase which leads him to recommend Micro-AV to his friends and family, and write a positive review on the Micro-AV website.

The Customer Journey Map is only meant to be a representation of a single future potential

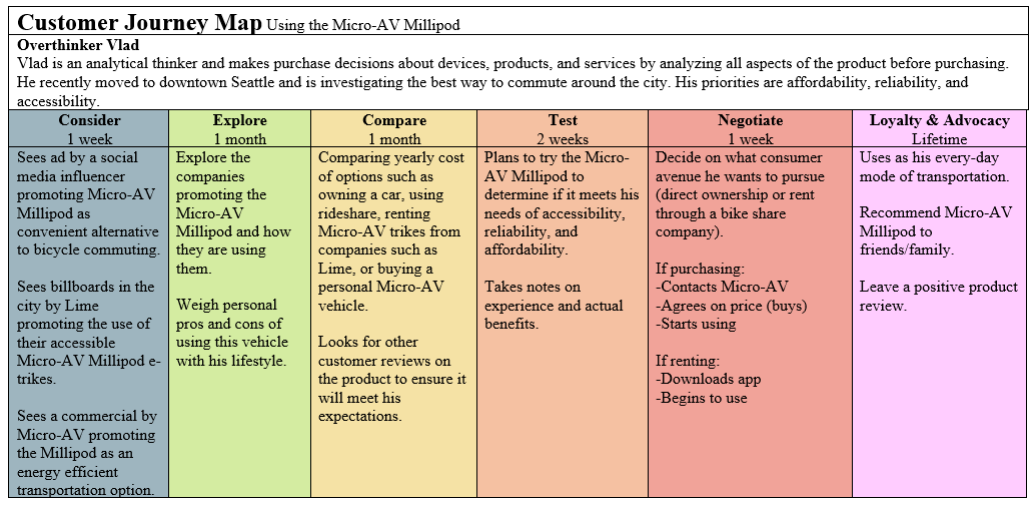
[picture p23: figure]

customer and does not encompass every individual experience. For example, a company such as Lime, Uber, or Amazon would have different priorities and therefore a different process of deciding whether to purchase Micro-AV Millipod trikes.

A.1.2 Design Strategy – User Insights and Research, Stakeholder Framing. Stakeholders Map/Matrix of Power

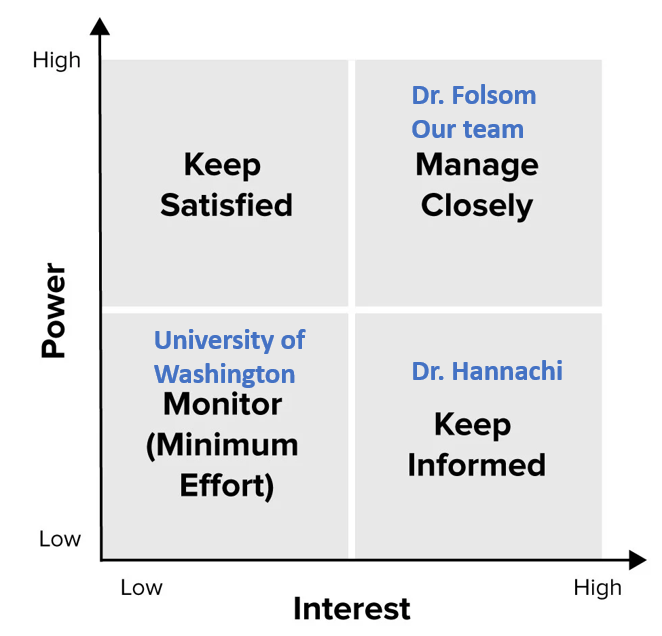
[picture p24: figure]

The Stakeholders Matrix of Power shown above serves to outline the people or entities with interest in this project, and the level of interaction each will have in the process.

Dr. Folsom has high interest in this project because he is investing money into it in hopes of patenting a method of platooning between vehicles with our product. Since he is also the sponsor of this project, he has a high amount of influence in the project as well, which means he has a high level of interaction with the project and his needs must be managed closely. This management will be conducted through weekly meetings for updates and feedback on the design.

Our team has high interest in this project because it is an interesting mechanical problem to solve, is a requirement for graduation, and provides hands-on experience in our field. We also have a high influence on the project because we are in charge of conducting the project and making design decisions.

Dr. Yoon has high interest in the project because he wants his students to succeed and graduate. He also has some influence on the project because as the academic advisor, he is a resource for design suggestions.

Dr. Hannachi has high interest in this project because she wants her students to succeed in their capstone and continue on to graduation. However, she does not have much influence on the project so she must be kept informed but will not be as involved with decisions.

The University of Washington has some interest in the project because it is a requirement for engineering students to graduate, but they do not have much interest or influence on the project. They will be informed of our progress in the form of a capstone grade, which will result in graduation.

Other potential stakeholders are future customers or users of the product. The first implementation of this product would provide a proof of concept to show that two vehicles can be mechanically and electrically connected together. This proof of concept is necessary to further Micro-AV’s goal of platooning multiple vehicles together for future use in multiple industries. The trikes that the product will connect will not exceed a maximum speed of 20 mph, if they are operated in bike lanes. If our product is successful, it will provide a good base for Micro-AV to expand and potentially patent more inventions and ideas. If the future products and inventions from Micro-AV were to become widespread throughout many cities and adopted for mass transit, regulatory entities such as the FTA [1] would need to be consulted to ensure adequate safety demonstration and smooth integration into the transportation system. In this case, years of small-scale application could serve as a safety demonstration. This is not something that is in the direct scope of our product, but it is important to consider for the future iterations of our product.

A.1.3 Design Strategy – User Insights and Research, User Scenarios and Personas.

When looking for a different way to travel around the city, there are many reasons why users would consider using Micro-AV Millipod trike, which requires our product (coupling/decoupling system) to connect them.
- Reduce carbon footprint by using a small, electrically powered e-trike
- Financial savings due to low energy cost and not needing to own a full size vehicle and pay for gas/etc.
- Convenience of autonomous driving
- Accessibility to people who either can’t own a full size vehicle or ride a regular e-bike/scooter

Taking these motivations into consideration, 3 descriptions of future user scenarios are described in further detail below.

Scenario 1: Mackenzie (age 24) lives in the suburban area near the city. She has an older vehicle that she uses to commute to work, but since she doesn’t like driving and her car is beginning to have issues, she is considering finding a new way to commute to the city. Her main objective is to save money, as she is looking to purchase a home in the next 5 years. She is also environmentally conscious, so she wants to reduce her carbon footprint as well. One option she has considered is taking the bus, but the route does not stop close to her work so she would have to walk the rest of the way. She also wants the flexibility to drive to other places in the city outside of the bus route.

If directly purchased a Micro-AV Millipod trike:
Pains:
- Initial cost of vehicle.
- Cost of insurance and repairs.
- Insecurity of new technology and lack of options in repair or choosing.
- Small vehicles have a lack of space for transporting goods.
Gains:
- Reduce carbon footprint.
- Long term saves money by not needing to buy a full-size vehicle and with reduced energy costs of the small e-trikes.
- Convenience of using autonomous driving.

If rented Micro-AV Millipod trike from bike-share company:
Pains:
- Lack of availability during peak hours.
- Small vehicles lack space for transporting goods. Gains:
- Reduce carbon footprint.
- Save money.
- Convenience of using autonomous driving.

Mackenzie’s general objective is to purchase a home, which means she must prioritize saving money. The timeline is 5 years (assuming she has some money saved already), which is estimated to understand it is a goal she is looking to achieve quickly. This is an important thing to note because the gains in this scenario mention long term financial savings, which may not benefit her goal since she is prioritizing a home purchase and needs to save money in the short term. The initial cost of a vehicle is a pain associated with any new vehicle purchase, but since she is prioritizing the short term financial savings, she will not buy a new vehicle.

However, she may still be interested in using a Micro-AV Millipod e-trike through a bike-share company because it allows her to realize the gains without the pain of the initial cost of the e-trike. Since Mackenzie is environmentally conscious, using an e-trike as transportation is appealing to her because it will help reduce her individual carbon footprint. Also, she does not have to drive anymore with the autonomous driving capabilities of the Millipod e-trikes. But a pain that concerns Mackenzie is potential unavailability of the e-vehicles during peak operating hours, as she does not want to be late to work if she cannot get a ride. If she decided to use this method of transportation, she would need to trust that the company supplying the Millipod trikes could keep up with their customers' demand.

If Mackenzie decided to rent an e-trike through a bike-share company, she could order one through an app and input her destination and the e-trike would arrive to pick her up and automatically drive her to work utilizing the bike lanes.

Scenario 2: Lime is a bike-share company that offers e-bike and e-scooter rentals in major cities. One of the problems they are experiencing is the abandonment of their e-bikes and e-scooters in random areas, as stated in many online articles. Their current solution is to pay people to pick them off the streets and charge them in their own homes, which heavily relies on people’s willingness to do such tasks [2]. They are currently looking for other solutions to redistribute to high-demand areas, and to return their e-vehicles to charging stations.

Purchasing Micro-AV Millipod trikes:
Pains:
- Initial cost of purchasing fleet.
- Maintenance of more complex systems.
Gains:
- Increase usage by redistributing to high-demand areas.
- Automatically go to charging stations.
- Appeal to people who can not operate a normal e-bike or e-scooter.

Lime’s main objective is to increase the use of their environmentally friendly transportation method. They are currently paying people to pick their e-vehicles up off the street, charge them, and replace them in high-demand areas. When making a decision about adopting a new solution, they must compare the pains and gains of their existing solution to the new solution. The main drawback of switching to Micro-AV Millipod trikes would be the initial cost of purchasing the fleet, and the maintenance of the more complex systems. However, compared to the opportunity cost of their vehicles being left in areas they won’t be used, and having to pay people to collect, charge, and redistribute the e-vehicles, this cost may not be significant. Additionally, the autonomous e-trikes would appeal to people who can not operate a normal e-bike or e-scooter, opening up a new customer type for Lime.

If Lime adopted the Millipod e-trike into their fleet, they would expect customers to be able to conveniently use their phone to order a ride that would pick them up and automatically take them to their destination utilizing bike lanes.

Scenario 3: Uber is a company that offers small delivery services through the UberEats app. One of the problems they are experiencing is a driver shortage, which is leaving customers frustrated with canceled orders [3]. A solution to this problem may be autonomous deliveries by Micro-AV autonomous e-trikes.

Purchasing Micro-AV Millipod e-trikes:
Pains:
- Initial cost and maintenance of fleet.
Gains:
- Solution to driver shortage.
- Save money by not having to pay delivery drivers.
- Reliability.
- Reduce carbon footprint.

Ubers main objective of the UberEats app is to satisfy their customers with quick, affordable, and reliable deliveries. However, their driver shortage problem is preventing them from doing so by forcing them to cancel orders when there is no driver to accept. They also charge high delivery fees so they can pay their drivers, which means their services are not accessible to people looking to save money. If they adopted the Millipod e-trikes, they could offer
autonomous deliveries at reduced costs which would be affordable for more people. They also would not have to cancel orders due to a driver shortage because the drivers would not be required to run deliveries, which would result in increased reliability of their brand.

If UberEats adopted the Millipod e-trikes, they would expect their customers to be able to order from an app, and have an e-trike autonomously deliver their order quickly and reliably.

While these potential customer considerations are much further down the line than the development of our product at hand (the coupling/decoupling system to interconnect two trikes), it is important to consider the impact our product may have on transportation if proven to be successful.

A.1.4 Design Strategy – User Insights and Research, User Insight Report

The sponsor wishes to have a physical connection between the two autonomous recumbent tricycles in order to have a modular vehicle system. This would allow for transportation in smaller, more efficient vehicles, and more modules may be added as necessary for transporting more people or goods. One of the benefits of a physical connection between two vehicles is increased fuel efficiency, but the closer the vehicles are coupled the bumpier the ride will be. Therefore, an effective spring/damping system must be designed to lessen this effect. Another key requirement is the desired capability for the vehicles to couple and decouple while in motion. Since there are a lot of variables influencing the position of the two vehicles being controlled autonomously, the coupling process may not be super precise. There are many different coupling mechanisms to be used between two vehicles, but this problem requires one that functions under loose tolerances.

Other important design factors are the space constraints, mounting scheme, and height adjustability specific to the geometry of the two trikes. The sponsor mentioned that there will be a mount on the front of the trikes for Lidar/Sonar, and the front arm of both trikes are adjustable to accommodate riders of different heights. Also, the rear end of both trikes have different luggage carriers to hold the electronics.

The key learning from discussions with the sponsor was the problems associated with physically connecting the two vehicles. It is important to be aware of potential issues and constraints so that the final product will be compatible with the vehicles being used to test it.
The solution would lead to the ability to physically connect two vehicles without causing a bumpy ride. The benefits of this connection are better fuel efficiency and the ability to synchronize a transportation route for more time efficiency.

A.2.1. Design Strategy – Problem Understanding and Framing, Product Assumptions Outline

The benefits the sponsor would like to experience from the solution are better fuel efficiency, a smooth and safe ride, and the ability to synchronize a transportation route for more time efficiency. To address fuel efficiency, the vehicles must be connected as closely as possible. But to prevent a bumpy ride, the connection must have an effective spring/damper system within it to absorb the low speed impacts due to differences in the vehicles speed and position. This connection must also be manufactured from adequate materials to ensure it is safe and does not fail under the tension, compression, and shear stresses it experiences. And to address the ability to synchronize a transportation route for time efficiency, the vehicles must be able to couple/decouple while in motion so that the string of coupled vehicles does not have to stop to pick up and drop off passengers. Three partial needs statements for these benefits are as follows:


Partial Needs Statement 1

Partial Needs Statement 2

Partial Needs Statement 3


A.2.2. Design Strategy--Functionality (tasks and associated outcomes)

In the section below, the functional requirements of each of the needs statements are provided. The objective of this section is to identify the requirements of the product to alleviate pains felt by potential users.

List of functional requirements for PNS #1:
- Must have a safe low impact collision when docking.
- Must be able to absorb impacts from worst case scenario velocity differentials.

List of functional requirements for PNS #2:
- Must create a mechanically and electrically sound connection between two vehicles
- Materials must withstand stresses introduced from coupling and velocity differences while driving.
- Materials must be low-cost.

List of functional requirements for PNS #3:
- Trike coupling/decoupling systems must be able to dock/undock at a safe rate for passengers.
- Trike coupling/decoupling systems must be able to attach and detach from the fleet quickly and safely for user convenience.
- Must be able to have a safe low impact collision when docking.
- Must have a reasonable gathering range to accommodate error in the control system.

How will we know if our product is successful?
The product will be considered successful if the system can demonstrate reliable and automatic coupling and decoupling as well as the ability to remain coupled and provide a smooth ride. The goal is to use a prototype on the Micro-AV autonomous trikes to demonstrate the coupling capabilities. Proof of concept for physical coupling capabilities will be a large step towards the development of modular vehicle systems. This proof of concept would also be a large step towards Micro-AV attracting partners to commercialize the product.

A.2.3. Design Strategy--High-level Constraints on the Usability of the Product

In this section the high-level constraints for each of the needs statements are provided. The objective of this section is to identify constraints of the product to alleviate user pains.

High-level constraints for PNS #1:
- Vehicle speed differences must not exceed 5-10 mph in order for the product (coupling/decoupling mechanism) to be able to function properly

- Product must be able to absorb shock from the impact of collision for optimal user experience

High-level constraints for PNS #2:
- The total cost of the product must not exceed the budget amount of $1,360 ($400 provided by sponsor and $960 provided by the school)
- Product materials must withstand operation of 10 hours per day for 10 years (assuming 4-8 couples per hour)

High-level constraints for PNS #3:
- The product must be able to couple and decouple at a safe speed, providing a low impact collision when docking, for the user so that there is no user discomfort
- The product must be able to quickly attach and detach for optimal user convenience
- The product must have a reasonable gathering range to accommodate any errors in the alignment of the coupling process

Combining all of these high-level constraints together, we can determine our final needs statement for the product:

The product is a fully automatic coupling and decoupling system that will interlock two vehicles while in motion, absorb low speed impacts from the collision of coupling, and retain the bumper-bumper mechanical and electrical connections to allow for a modular vehicle.

A.2.4. Design Strategy--Final Needs Statement and User Outcomes

Final Needs Statement
The product is a fully automatic coupling and decoupling system that will interlock two vehicles while in motion, absorb low speed impacts from the collision of coupling, and retain the bumper-bumper mechanical and electrical connections to allow for a modular vehicle.

What does our client want from the product?
Our client wants a coupling mechanism that can automatically couple and decouple two vehicles, and maintain bumper-bumper connection while driving. The client also wishes for an electrical connection to be established between the two vehicles.

What are our customers' pain points?
Our customers’ current main pain point is inability to attract partners to commercialize their product. This is due to a lack of a working prototype to prove their concept of the modular vehicles.

How can our product solve these pain points?
Our product can solve these pain points by demonstrating the automatic connection between two small vehicles to form a modular vehicle. Once the prototype of the coupling mechanism is proven to be effective, Micro-AV will gain funding and support from partners that will help them commercialize their Millipod vehicles for bike-sharing or small delivery purposes.

A.2.5. Design Strategy--Hypothesis Statement

Our direct clients, Micro-AV, require a proof of concept for physical coupling mechanisms between vehicles as a crucial component of the proposed system of modular vehicles being developed by Micro-AV. The solution will satisfy the requests of the client if it can serve as a proof of concept for an physical system that can automatically couple and decouple with specified control signals, as well as stay coupled under dynamic loads as provided by the operating conditions designated by the client. If this system which is built is compatible with the provided vehicles to test and passes simulation conditions as defined by the project requirements, this project will be successful.

The hypothesis is that physically connected vehicles outperform platooning vehicles in fuel efficient, autonomous, synchronized travel. This is due to the physical couple and damping system correcting for errors in the control system of the vehicles. Additionally, vehicles traveling in platooning formation still suffer from some amount of aerodynamic drag, that of which is minimized when following distance between vehicles is minimized. The most practical way to safely achieve this minimized following distance is through physically coupling them.

A.2.6 Design Strategy--Possible Inventions and Business Model

Below are listed possible inventions for the coupling and decoupling product. Each possible invention has been ruled out of our consideration for various reasons due to assumptions and constraints required from the final product.

Invention #1:
Utilizing an electro-magnet system to couple and decouple the trikes when within an acceptable range.
Systems Level Sketch Invention 1


Invention 1 was not feasible because it would be difficult to control the collision between the two trikes if using magnets to couple. It would be hard to dampen the forces from the collision to an acceptable level for user comfort. Invention 1 would also require very strong magnets which would be both very heavy and costly.

Invention #2:
Platooning enabled by wireless information transfer which can be used to inform vehicles to control distance between one another. Utilizing WiFi or other forms of wireless communication between vehicles, signals containing information vital to road operation would be collected using proximity sensors, GPS, lidar, or other similar mechanisms. This information would be transmitted between all vehicles within a specific range, allowing their driving to be informed and synchronized to the point of platooning.

Systems Level Sketch Invention 2


Invention 2 is not considered to be desirable due to the fact that platooning is not as energy efficient. Without physical systems to couple, this system is limited by how close vehicles can safely operate to each other, which will ultimately limit the amount of energy usage reduced.

Invention #3:
Utilizing interchangeable male and female coupling parts in a system alongside a dampening device (such as a bumper) in order to couple and decouple two trikes both mechanically and electrically.

Systems Level Sketch Invention 3


Invention 3 is feasible and provides all the necessary components desired for our product. Invention 3 provides the scope of a product that is a fully automatic coupling and decoupling system that will interlock two vehicles while in motion, absorb low speed impacts from the collision of coupling, and retain the bumper-bumper mechanical and electrical connections to allow for a modular vehicle.

Lean Canvas


A.2.6.1 Design Strategy--Final Invention

The physical coupling solution was chosen because it allows for a modular vehicle such as the Millipod to operate with increased fuel efficiency, synchronization, and enhanced autonomous capability. This solution will be deployed on the e-trikes as well as the Millipods. This physical coupling solution will play a significant role in fulfilling the visions of improving fuel economy and reducing environmental footprints.

These Millipods will then be used by both urban commuters directly as well as public and private entities who would distribute products or services. Important marketing factors such as scale and configuration can be assessed based on research pertaining to the four urban city archetypes: rising megacities, established megacities, car-dominated mature cities, and mature advanced cities. The scope and scale of the deployed products would adjust according to specific city needs based on this criteria.

To reach these desired customers, outreach will coordinate with government and private entities to deploy products. A mode of flowing demand from urban commuters to such entities that is heavily in consideration is through the use of mobile applications, either new or existing, to

“book” or “order” such services or products. This could function in a way similar to Lime scooters or Uber. Supportive capabilities could also be added to apps like Transit which detail public transportation. Revenue could be earned through different avenues, primarily selling the units themselves and possibly renting them out.

A.2.7 Design Strategy – Product Planning Roadmap

The main features of the product for the scope which will be worked within will be the bumper, physical coupling system, and electrical connection.

The main function of the bumper will be to damp the forces from collisions. The fit of this bumper will be intended to be modularly compatible with different μAVs. The form of the bumper will accommodate the physical coupling system. Within the scope of this project, the bumper is to be designed to house the physical coupling system strictly. However, for future product development occurring outside of the project scope, the bumper will also implement sensors that will provide positional information and proximity to other vehicles. This comprises the bumper’s planned functionality.

The physical coupling system is to couple and decouple the vehicles when appropriate. When coupled, the vehicles are to stay coupled during operation until the system is otherwise instructed. Two different structures must be designed, one female connection and one male connection, to accommodate front and back linking between multiple vehicles. Due to the current stage of maturity of the vehicles utilizing the coupling system, proximity sensors will be not implemented into the design but planned for. As a result, the design of the coupling system will utilize a purely physical coupling initiation. Digital components will not be required at this point in development.

In mechanically developing the two systems, teams can be assigned between bumper and couplers. The bumper must first be engineered to absorb a certain amount of shock in specific instances to protect the rest of the vehicle. The couplers will then be developed, using the bumper as a housing of sorts. This comprises the scope of development for this project. At the end of this project, a bumper system that houses a primarily mechanical coupling system will be built and attached to the provided vehicles that would provide a proof of concept.

For future product development, electrical and software systems will be introduced into the coupling systems. Electrical proximity sensors that can identify distance between vehicles and verify coupling and alignment will be important to allowing autonomous operation. Additionally, within the couplers, wired connections enabling vehicle to vehicle communication will be pursued. Lastly, software must be further developed to enable autonomous vehicle operation and navigation. This would include a fully autonomous coupling and decoupling process as well.

Product Roadmap

This project will be supported by four primary functional roles: Project Manager (Devin Taing), Outreach (Li-Ling Plume), Lead Mechanical Engineer (Rebecca Sasten), and Technical Lead( (Vladimir Roca). The project manager will be responsible for managing the budget and coordinating the timeline of all technical tasks. Outreach will be responsible for managing and flowing information from all communication external to the team. The lead mechanical engineer will be the subject matter expert for technical research and development. This also includes ensuring the compatibility and integration between different systems i.e. bumper and coupling. The technical lead will be responsible for testing, prototyping, and physical production needs. This includes generating test methods as well as executing them, and generating reports to communicate. It should be noted that all of the roles will be intermixing with one another and that these are assignments of responsibility, not activity.

Technical responsibilities will also be primarily group-based, but generally owners of responsibility will be divided in terms of research and knowledge ownership, while design decisions will be made collectively. Subject matter ownership can be split up between bumper design, front coupling design, back coupling design, and operating condition requirements.

Product Development Timeline


B. Experience Design
B.1 Experience Design – Human Interface Design, User Workflow

This project consists of developing a mechanical system/product that can couple and decouple two trikes. These trikes will ideally be used in a platoon composing the Millipod, however this will be in later iterations of the product. The product must be able to couple two trikes front-to-back and back-to-front, therefore being interchangeable. This product will consist of a male and female part which will interlock once within an acceptable coupling range. The product will be able to couple while the trikes are in motion. There will be adequate shock absorption from the collision caused by coupling through the use of bumpers along the front and rear of the trikes. For the first product, the user will press a button to indicate that they are ready for coupling. Once the button is pressed the product will begin to couple and will mechanically interlock. After mechanical interlocking, the electrical connections will engage. The utilization of the user pressing a button to indicate the start of coupling is only necessary for this scope of this project and will be replaced by a signal from the vehicle control system in later iterations. The user will optimally experience seamless coupling and decoupling with adequate shock absorption.

User Experience Flow Diagram


B.2 Experience Design – Human Interface Design, Environmental analysis

Various assumptions that must be made for the product to be operational are listed below along with design constraints resulting from human interface with the product.

Product Requirements:
1. The product must operate on flat road conditions with minimal turns when coupling and decoupling.
2. The maximum speed differential between the two trikes during coupling must be within a range of 0-5 mph, with a maximum of 10 mph between the two trikes.
3. The product must dampen/absorb the shock associated with the coupling process.
4. The maximum speed the product must withstand when coupled is 40 mph.
a. If the trikes housing the product operate within a bike lane the top speed will be reduced to 20 mph.

Product Expectations:
1. The product will be expected to couple and decouple 4-8 times per hour.
2. The product will be expected to operate 10 hours a day.
3. The product will have an adequate tolerance range in the X, Y, and Z direction in order to assist the coupling process.

Expectations of User’s Interface/Experience:
1. The product will be mounted to the front and back end of the trike. The front end of the product will be mounted on the existing foot pedals of the trike and the user footrest will be relocated out of the way of the coupling/decoupling process.
2. The user will press a button to indicate when it is safe to start the process of coupling or decoupling. As aforementioned, this will be replaced by a signal from the vehicle control system in later iterations of the product.
3. The user will not experience any jolting with coupling that may cause discomfort.
4. The user’s extremities will not be at risk of getting caught in any of the coupling and decoupling processes.

B.3 Experience Design – Human Interface Design, Cultural factors mapping

The design is primarily for city and suburban use. We analyzed both the United states and internationally to see how certain cultural factors will affect the design of our coupling system. Here are the 5 cultural characteristics:
Learned: We learn culture from family, peers, institutions and media.
Shared: When we share culture it allows us to act in a societal way and predict how others will act/react.

Symbols: Must have a group of people agree on the meaning of a symbol to use. (language for example)
Integrated: Holism, as one culture is not defined by a singular thing but is interconnected to multiple different parts that make it whole.
Dynamics: Most cultures are in contact with other cultures and this causes us to share ideas and adapt to changes in society.
These characteristics will directly affect how effective we are in designing something that is human centered. Although it is hard to measure the characteristics of culture depending on the country, we can generalize the idea to give us a better understanding on how it affects our design. When designing a product within the US, the dynamics and integrated portions of the characteristics is a higher factor since the United States is a melting pot of multiple cultures. This causes us to take into higher consideration how those factors will affect the coupling design. The most important characteristic that is equally affected internationally, is Symbols.
A vehicle/trike can symbolize multiple things, this depends on how together as a group, a village, city, state, or country views something and agrees upon that something. Since language is a symbol in which we can agree on the meaning of something, language is our main factor. When we say vehicle/trike we think of a transportation device first and then other factors follow along.
So when designing a vehicle/trike that transports people or things, we must automatically try to fulfill the idea of the word vehicle/trike. This is important if the desire is to have better adaptations for all different cultures.
Next we must take into consideration what the expectations of what a vehicle/trike is. Traditionally a vehicle/trike is thought to be a transportation device that you must operate at all times. When designing something new that breaks the norm of what was thought previously, we must take into consideration how we are adding value to the symbol of the word “vehicle/trike” and how that will affect the culture within that environment.
The impact within each human interaction will be affected by how we redefined the word vehicle/trike. Since autonomous vehicles coupling in platoons is a new idea of transportation we will aim to add value and create a design that can be accepted by many different cultures. Internationally the micro-Av will be of benefit depending on the transportation system that each country operates under. Questions such as, what type of terrain is there? Is there service? And much more is critical. Accessibility would vary depending on the country so when designing the micro-Av coupling system we must take into consideration different terrains to give every human the same experience when using the micro-Av. This means we must try to design to still operate under the worst terrain possible, depending on our target environment . This helps later for all cultures to experience the same thing which then can provide similar issues or positive results. Each industry will also vary since certain cities even within the united states are highly populated so addition and transition of a new transportation would not easily be welcome to the public. When thinking of the dynamics of culture, it will depend on how the transition happens. New York for example is a dense city and the transition would be critical since it is a fast paced environment. Even if humans were open to the benefits of the micro-Av, the transition would factor higher how they would communicate about the new transportation system with the micro-Av. In contrast, other cities that are not dense, if they applied the micro-Av as a part of their transportation system, they would share the benefits to one another, eventually if accepted by the people of one location it will be known as a part of their culture on how they transport themselves or items.
Since the environment changes per culture, it can be concluded that each design must first view the environment and in line see how culturally it would be accepted by the group of individuals in different regions of the world.

B.4 Experience Design – Human Interface Design, Information Architecture and Hierarchy

Using the user experience flow diagram and information gathered in B.2. A list of inputs and outputs can be created to ensure that the design is human-centered at all stages of the workflow.

User presses button to indicate start the coupling process:

Human-centered inputs user/device:
- Visual representation of the button
- Location of button
- Force required to press the button.

Human-centered outputs user/device:
- Visually able to distinguish between other buttons or surfaces.
- Location is accessible for better performance.
- Pressing a button that does not take too much force but enough to recognize the switch.

Collision between the two trikes are damped by bumper system:

Human-centered inputs user/device:
- Force and speed of impact
- Distance of trikes

Human-centered outputs user/device:
- No shock felt to passenger or items during collision

Mechanical system begins coupling and interlocking:

Human-centered inputs user/device:
- External/internal forces and vibration due to terrain

Human-centered outputs user/device:
- Passenger would not likely notice the trikes are coupling

Electrical connection engages:

Human-centered inputs user/device:
- Mechanical switch triggers electrical response.

Human-centered outputs user/device:
- Electrical message is sent to connect within the coupling system.
- Coupling system is an external device, no electrical wires are exposed to passengers.

Trike is mechanically and electrically connected:

Human-centered inputs user/device:
- Mechanically closed
- Electrically closed

Human-centered outputs user/device:
- Coupling device understands it is electrically and mechanically connected.
- Passenger would not notice anything happening when system is being coupled

Trikes are interlock and can begin to move as one:

Human-centered inputs user/device:
- Ready to move

Human-centered outputs user/device:
- Passengers would not notice anything happening when the coupling system is completely coupled.

B.5 Experience Design – Human Interface Design, Analog Interface Design

Since the end product of the coupling device will be fully autonomous, there would be no analog interface for humans to interact with. However, for the purposes of this project, some steps in the coupling and decoupling of the mechanism will require intervention in the form of pressing a button. For this design, the electrical connection will be made after the physical connection is secure by using an actuator controlled by a switch or button. In future iterations of the design, this switch will be replaced by a signal from the vehicle's control system.

If the Millipod system is used to transport people in the future, the design of the vehicle pods must be comfortable for the user to sit in, as well as easy to get in and out of. For the scope of this project, the only comfort feature that will be added is foot rests on the front of the Micro-AV trikes so the user can comfortably ride in them without having to hold their feet up. The foot rests will be installed on adjustable pegs to accommodate different rider heights and allow for ease of adjustment before riding.

B.6 Experience Design – Human Interface Design, Graphic User Interface Design

There is no graphic user interface involved with the coupling device. However, the graphic user interface for the entire Millipod system will most likely be in the form of an app users may download on their smartphone, similar to rideshare or food delivery apps. If the Millipod is used to transport goods to people's homes, this app would have features allowing the user to select items, schedule deliveries, and track their shipments. In the future, the Millipod technology may be adopted into the larger transportation system, in which case this app would allow users to schedule their route and notify them when their vehicle pod will arrive.

B.7 Experience Design – Human Interface Design, Best Use Practices Report

There are multiple failure modes that are possible for this project. This includes mechanical and electrical failures. For mechanical failures, the coupling system may not maintain physical connections, causing the components to yield or break under the stress of operation. This would result in the coupling mechanism to detach from itself or from the mounting at an undesired time.

Another possible point of failure may be inaccuracy during coupling. As a result of this inaccuracy, the vehicles to be coupled may not make the necessary contact to physically connect them, thus not completing project requirements.

Lastly, electrical failures could occur. Any event which would dampen or disrupt the electrical signals carrying either information or energy between vehicles. Electrical connections may be disrupted through physical means, such as insufficient mechanical methods of maintaining coupled status, or the introduction of other substances which would interfere such as moisture or dust.

The desired end-product in which this coupling mechanism will be applied intends to be fully automatic. As a result, the user would not need to directly interface with the coupling mechanism which this project’s scope focuses on. As such, best use guidelines would not be necessary for the rider. Instead, failure would be prevented by ensuring proper maintenance protocols are established once the design of the product is finalized. Maintenance would be primarily analog, checking for the health of the mechanisms throughout its operational life.

Once the design life is finalized, the frequency of maintenance checks on the coupling system can be determined in combining financial and engineering considerations. Depending on the frequency of maintenance checks on the coupling system, different types of maintenances checks may be deployed, but all will ultimately check for things such as: a) health of moving parts, b) health of impact dampers, c) health of overall structures and housings, and d) verification of electrical connection pins. The methods used to evaluate these indicators of system performance is yet to be fully determined.

System Maintenance Plan
Component | Health Indicator | Test Method | Frequency
Moving Parts | Full, smooth movement within designed range of motion, no squeaking | Undetermined | Undetermined
Impact Dampers | No signs of wear and damage such as cracks, rust | Undetermined | Undetermined
Structures / Housing | Absence of audible/visible signs of damage or wear such as cracks, rust | Undetermined | Undetermined
Electrical Connection Pins | Transfer of current/ power/information when in contact | Undetermined | Undetermined

B.8 Experience Design – Human Interface Design, the Summary Document, in essence a Usability Requirements Documentation.

The requirements of the coupling system will not be driven heavily by aesthetic considerations. As a result, the considerations of form will not be weighing heavily into the design of the coupling system. Instead, the function of the system will be a much more prominent design driver. In addition to the function of the system, the comfort of the riders will be of much higher importance. In terms of aesthetic possibilities, as long as the coupling system generally fits with the visuals of the existing system it is being integrated into. Another possible consideration visually is to have the material of the system be one which can be painted over to have greater flexibility visually.

C. Requirement Documentation
C.1.1 Design Decisions and Rationale

Given the chosen design, the final product will likely be machined and manufactured in house. The final product will consist of two male and female counterparts. The order in which the male and female counterparts will be built is yet to be determined, they may also be built simultaneously.

Female Counterpart


There will be two main components to manufacture for the female counterpart. The funnel of the female counterpart will be made of a tin funnel that can be cut down to size and attached to the rest of the female assembly. The base of the female counterpart will be made of a solid aluminum block. The slots and openings within the block will be machined with the 3-Axis CNC Milling Machine in addition to the CNC. The two pieces will then be welded together. The locking mechanism within the female counterpart can either be machined in house or purchased from an online supplier.

Male Counterpart


The male counterpart will consist of a main shaft, universal joint, and dampening system. The main shaft will likely be machined out of round aluminum stock that will be turned to size and shape on the lathe. Additional details on the shaft can also be machined in house with the 3-Axis Mill and CNC machine. The shaft will be TIG welded to a universal joint. This universal joint will be purchased according to spec and size from a supplier online. The dampening system will consist of a casing and spring welded to the back end of the universal joint. The casing will need to either be purchased online as hollow stock material (tubular or rectangular) or machined in house. The spring will be purchased online and will sit inside the casing.

The final product will be an automatic coupling and decoupling system consisting of a male and female counterpart as depicted above. The final product for testing purposes will consist of two complete sets of male and female counterparts mounted onto two trikes, the male counterpart will be mounted onto the front of the trike and the female will be mounted to the rear of the trike. There will be a simple mechatronic system consisting of a button that the user can press to initiate coupling or decoupling. When both counterparts are mechanically interlocked, there will also be three electrical connections that will accompany the system to provide electrical connections (two data connections and one ground connection).

C.1.2 Tier 1 Schematics (block diagram)

Level 1 Roadmap of Major Elements


There are a couple major elements in this design, which will be explained below:

Mounting
The mounting scheme does not appear in the schematic shown above because it does not play a significant role in the function of the coupler, as its only purpose is to provide an attachment between the coupler parts and the trikes.

Male Counterpart
The male counterpart will attach to the front of the trike and will serve as a connection point between the two trikes. This element is also responsible for accommodating the motion between two trikes and providing damping from low speed impacts. Within this element, there are several different parts that work together to fulfill those requirements.

Female Counterpart
The female counterpart will attach to the back of the trike and will work to lock the male part in place. This element is also responsible for accommodating for positional differences between the parts as the trikes are coupling.

Electrical Connection
The sponsor also wishes to have a 3 wire electrical connection established between the two trikes. For the scope of this project, this connection only serves the purpose of physically demonstrating the connection of the wires. However, in future iterations of the project an electrical connection will be important for inter-trike communications.

C.1.3 Tier 2 Schematics for each element (block diagram)

Level 2 Roadmap of Individual Pieces within Elements


The design consists of a couple major elements that will be mounted to either end of the trikes. The male part will attach to the front of the trike and consists of a shaft, universal joint, and damping system. The female part will attach to the rear of the trike and consists of a funneled receiver, and lever locking mechanism driven by motors. There will be a mounting scheme designed to attach the coupler parts onto the trikes. There will also be wired electrical connection between the two trikes with a high signal, low signal, and ground. The coupling will happen purely mechanically (with the trikes being driven manually by remote control). The decoupling will use a simple mechatronic system and be initiated by the user pressing a button. The individual pieces of each element are described and shown below.

Shaft (male part)


The unique shape of this part allows it to enter the hole in the receiver and also provides a secure surface for the lever locking mechanism to rest. The curved ball shape at the front of the shaft allows the lever to be pushed onto the shaft and drop into the groove behind it.

Universal Joint (male part)


A universal joint is used to accommodate for 90 degrees of motion in every plane (pitch, yaw, roll). This type of joint was chosen to imitate the McHitch design and can be purchased assembled with the yokes or separately.

Spring/Damper (male part)
The spring/damper will be responsible for absorbing forces introduced to the system by low speed collisions due to coupling or potential speed differences while the vehicles are driving.

An important consideration for selecting a system for this application is the potential for tension in the spring.

Receiver (female part)


The receiver has a funneled shape at the entrance to accommodate for errors in the alignment of the two vehicles before coupling. This will allow for the shaft to be a few inches to the left, right, top, or bottom of the receiving hole and still couple successfully.

Lever Locking Mechanism (female part)


The lever will be attached to the back of the receiver and will sit in the slot of the shaft while the trikes are coupled, similar to the McHitch design. A motor will be engaged, using a rack and pinion gear to aid in lifting the lever to allow decoupling. The motor will be activated by the user pressing a button, but in future iterations of the design this could be replaced by a signal from the vehicle's control system.

Electrical Connection
The sponsor also wishes for an electrical connection to be established between the vehicles through the coupler. This electrical connection will consist of 3 wires, one for high signal, one for low signal, and one for ground.

C.1.4 Tier 3 Schematics (concrete connections between blocks)

The design consists of multiple parts individually but collectively depend on one another. Here, the relationship between certain parts in detail to describe the interaction between them will be covered. The brief conceptual actions between each part will play on one another and how that will act collectively, so it must begin at the starting point. The main objective is to couple two dynamic systems so all parts will contribute to this action being completed. Below is the first relationship with the male part and female part (overall part). This should be looked at from the big picture and brought down to the specifics.
The male shaft will insert itself through the female part through a funnel which will cover the direction guidance factor for precise coupling and minimize disturbance caused by external factors. These factors are things such as overall bumps, vehicles not fully aligned, and etc. These factors are the forces acting of the male shaft from all directions and will be maximize during the beginning of insertion and once male shaft has fully insert it itself those external forces being applied from all directions will be negligibly small, and so focus can be directed on the linear motion of forward and backwards, working with a 2D problem rather than a 3D. To take care of the peak forces being applied to the male shaft and female part during the beginning of the interaction since they will be rigid parts additional material for the female part may be needed. Additional material selections will be worked through after main parts are built but ideally the funnel should consist of possibly additional material that would take care of vibrations and minimize direct contact of parts as it would eventually damage the funnel and male head shaft destroy its purpose. Additional material will also minimize notice of coupling interaction when the user is activating the action.
Next there will be a focus on how the male and female part connect to one another and the purpose of why each part is shaped differently. As noticed before the male shaft head is rounded to push the lever mechanism to the groove which is after the head that will cause it to act and hold on the groove that the male shaft has. These are the final forces acting between the male and female parts that cause no high amount of forces acting on one another, once lever has dropped in place to hold on to the groove. To not allow all direct forces of forward and backward to be on the groove of the male shaft an additional pin mechanism is added to take care of the forces of forward and backward. Since it is understood that the groove has a max measurement that is based on the diameter of the shaft, the high load will likely bend the lever that holds on the groove and for that reason an additional location is needed to take care of this issue. Having the pin will take care of the stress concentration being only applied to the lever and groove of the male shaft which is limited by the diameter of the shaft. Having a pin go through the male shaft gives of more space to allow the forces to act evenly and if failure was to happen that it would not snap if it was only on the male shaft groove and lever but for the male shaft to elongate and there to be visible failure so repair can be conducted and no spontaneous slip or snap of the groove.
The reason for selecting a motor based pin mechanism is to also take into consideration that the vehicle is autonomous and this will allow for easier interaction between locking mechanism and brain of vehicles but also if implications where to happen, any failures can be determined where motor itself is having instead of a purely mechanical mechanism that would have no interaction of its performance and notice of its failure. Additionally the U-joint and Yokes are to take into consideration the vehicle's motion of pitch for bumps and yaw for turns. Roll is not a major topic of consideration due to the fact that the vehicle should be on a road. The U-joint being mounted to the male shaft was due to the idea of having a steady female part, because the male part was already under a lot of motion and to apply motions to different places in this scenario causes more disturbances and increase the external forces that affect the male shaft and female part already.
Lastly the spring damper system will be attached to male part due to the following reasons. Since two vehicles are connecting to one another it can be assumed the vehicle behind will be trying to add speed to get closer to the vehicle in front to attach itself to. Since the vehicle behind is moving forward, and there needs to be a smooth and not noticeable coupling interaction, the part being on the male shaft is ideal since to increase life of the spring/damper system.
To conclude these are major interactions to no another and reason behind the design that is present here. Further analysis will determine the exact measurements of parts to create a suitable coupling design to suffice to any two dynamic systems operating on a road.
C.2 Estimation of cost of goods
Listed below is the Cost of Goods Chart pertaining to the materials necessary for the final product. This is currently a rough draft of what our chart/bill of materials will look like in the future. It currently cannot be determined exactly what is needed to order as the design for the final product is not yet complete or close to being complete, ordering will be conducted for materials once the design has progressed more. More research on materials and alloy compositions needs to be done before any items can be purchased.

Cost of Goods Chart

Link to access:
https://docs.google.com/spreadsheets/d/1FNnuN2hvXIVhPkbXcQaQ7vHTFL8sz9O7/edit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 (https://docs.google.com/spreadsheets/d/1FNnuN2hvXIVhPkbXcQaQ7vHTFL8sz9O7/edit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)

The items currently in the list are placeholders. Some items not listed in the spreadsheet above include materials for making or purchasing a locking mechanism for the male and female counterparts. There is no listing currently for plans to purchase the spring and tube for the damping system as greater specifications for those items still need to be determined. Additionally, support for mounting the male and female counterparts onto the trikes will be needed as well. This may consist of metal brackets. Additionally, items will need to be purchased for the simple mechatronics system controlling the engagement of the coupling/decoupling.

In addition to the raw cost of goods, the cost of machining and manufacturing in house into the budget, such as cost of supplies to weld, must be factored in.

C.3 Schedule

Technical GANTT Chart


Documentation GANTT Chart

Technical Tasks & Deadlines

Documentation Tasks & Deadlines

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


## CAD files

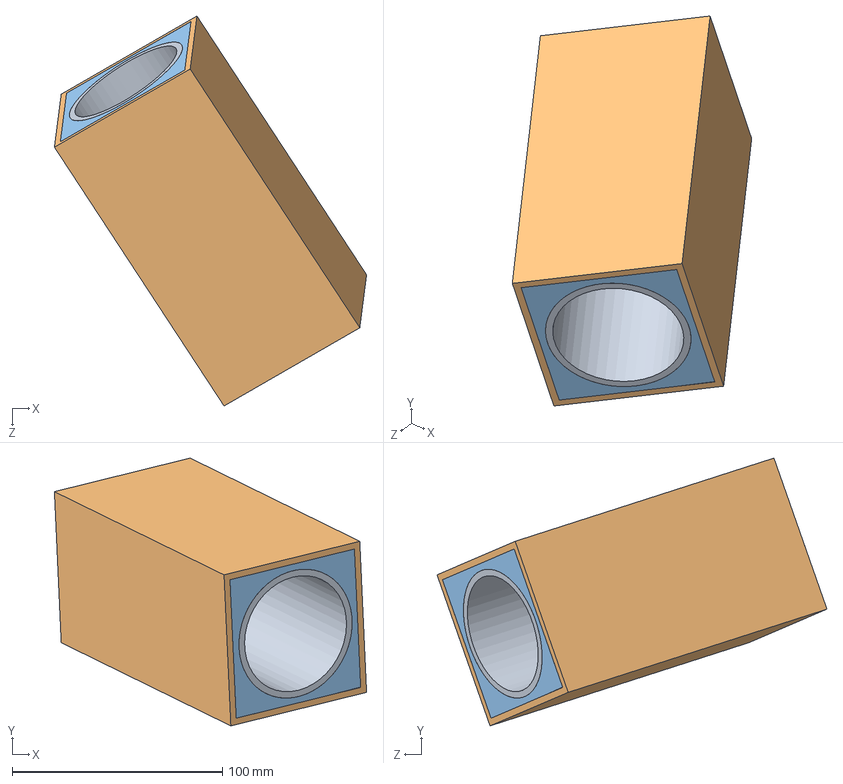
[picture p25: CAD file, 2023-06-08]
LinkedVehicles-Winter-Spring2023/CAD/New Female Part/Female Stock Assembly with Inserts.SLDASM
148.5 x 127.4 x 185.5 mm
Female Coupler Stock Materials
6546K651_Multipurpose 6061 Aluminum Rectangular Tube
3D printed insert x 2

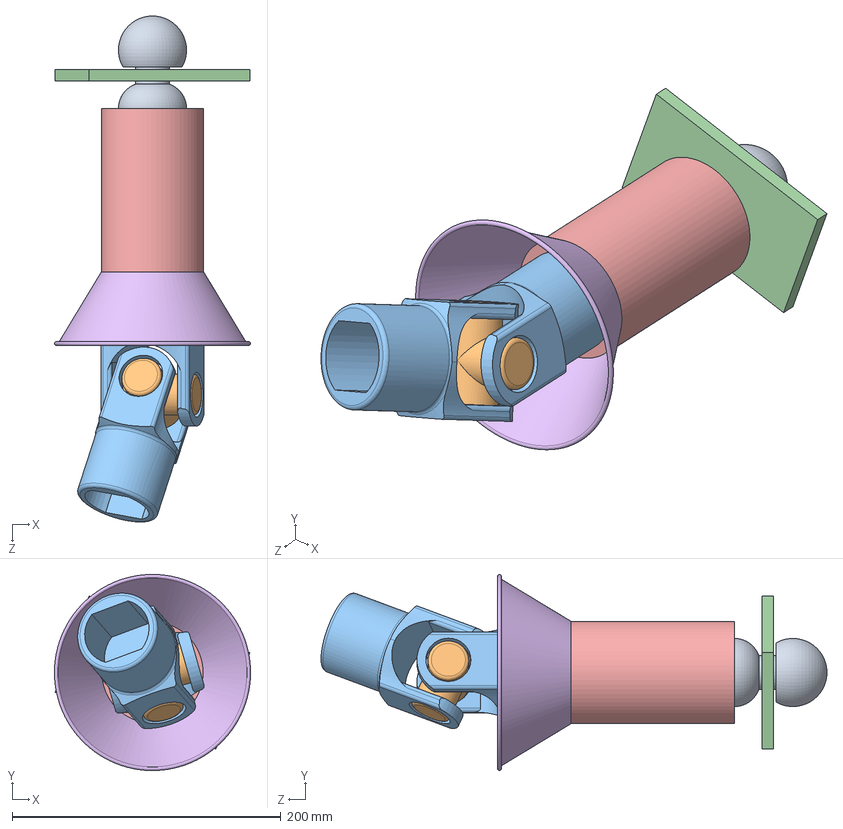
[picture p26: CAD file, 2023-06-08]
LinkedVehicles-Winter-Spring2023/CAD/male and female/male and female.SLDASM
146.0 x 146.0 x 376.7 mm
Male Shaft (2)
UJoint
Yoke2 x 2
lever lock
9056K221_Multipurpose_6061_Aluminum_Round_Tube (1)
8996T14_24_oz._Tin_Funnel Extrude Cut

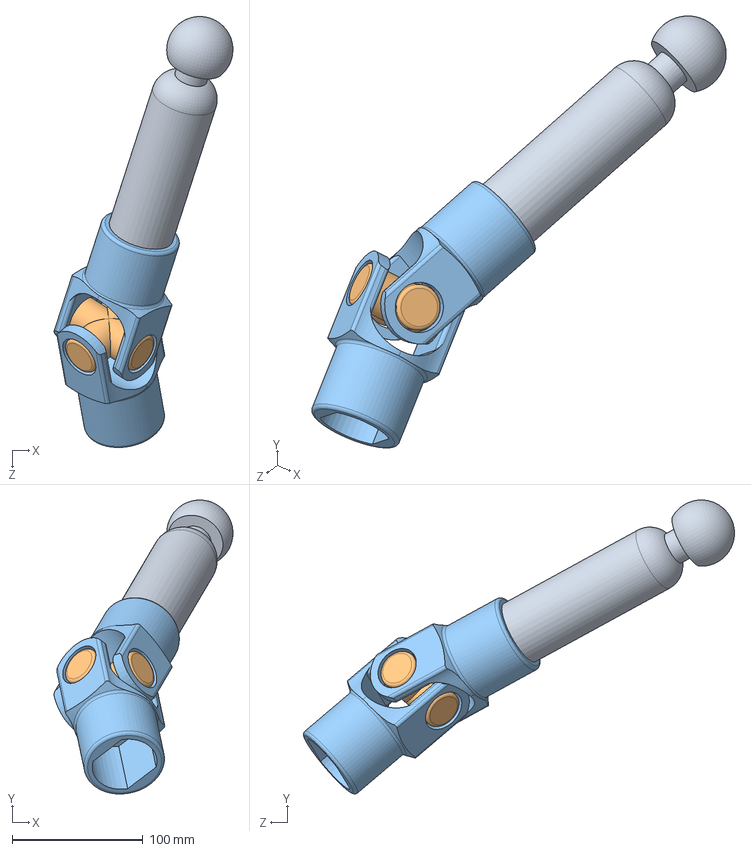
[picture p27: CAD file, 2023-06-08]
LinkedVehicles-Winter-Spring2023/CAD/Male/Male Shaft Assembly LP.SLDASM
137.1 x 225.3 x 330.2 mm
Male Shaft (2)
UJoint
Yoke2 x 2

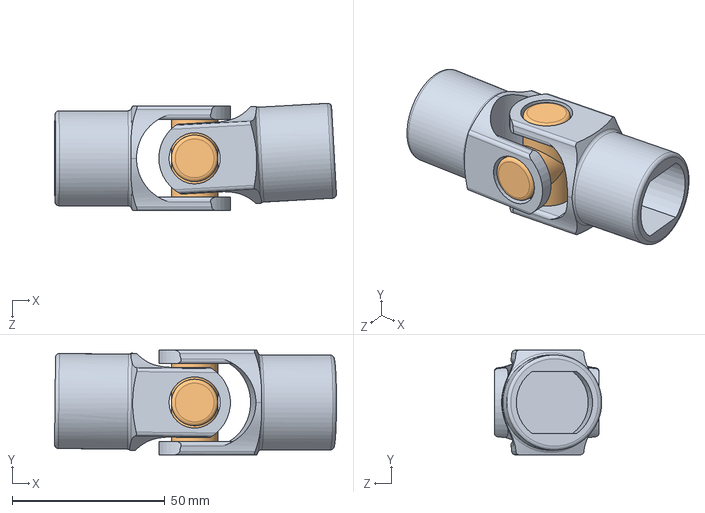
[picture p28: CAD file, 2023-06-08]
LinkedVehicles-Winter-Spring2023/CAD/Male/DD_UJoint.SLDASM
92.3 x 34.3 x 35.2 mm
Yoke2 x 2
UJoint

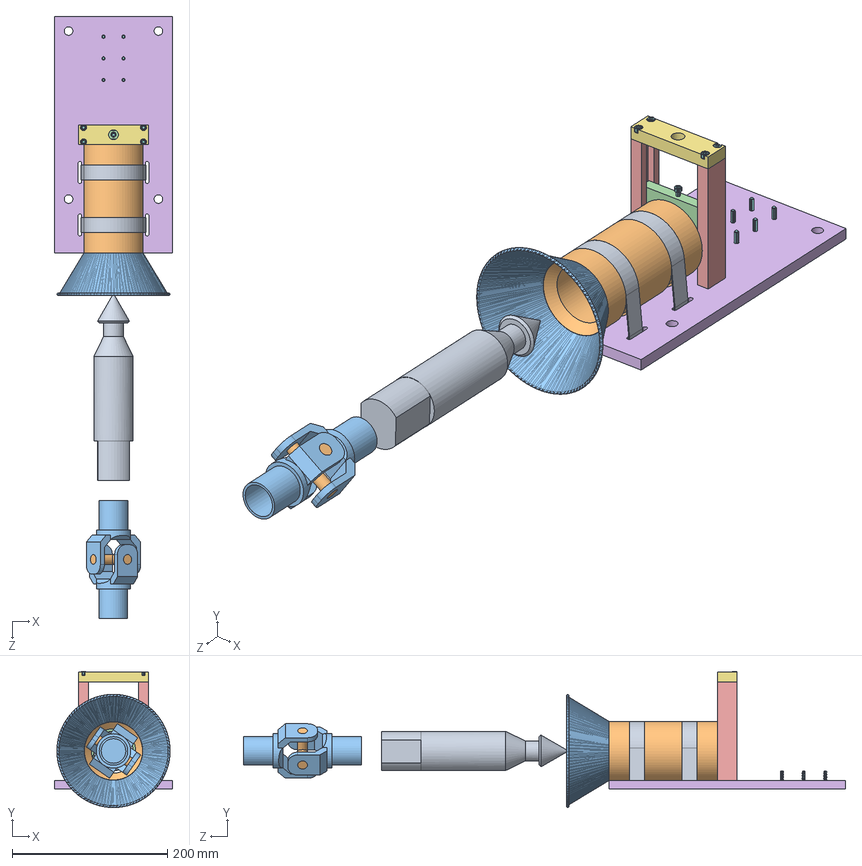
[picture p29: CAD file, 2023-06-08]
LinkedVehicles-Winter-Spring2023/CAD/Proto Lock 1.0/Proto lock 1.0.SLDASM
152.4 x 175.6 x 776.2 mm
9056K221_Multipurpose_6061_Aluminum_Round_Tube (1)
Male Shaft Pointed
Lever lock
Rail_tapped hole x 2
Base Plate
8996T14_24_oz._Tin_Funnel Extrude Cut
1x.5 barstock
90128A197_Zinc-Plated Alloy Steel Socket Head Screw x 15
Holding Bands x 2
CROSS
ARMS x 2

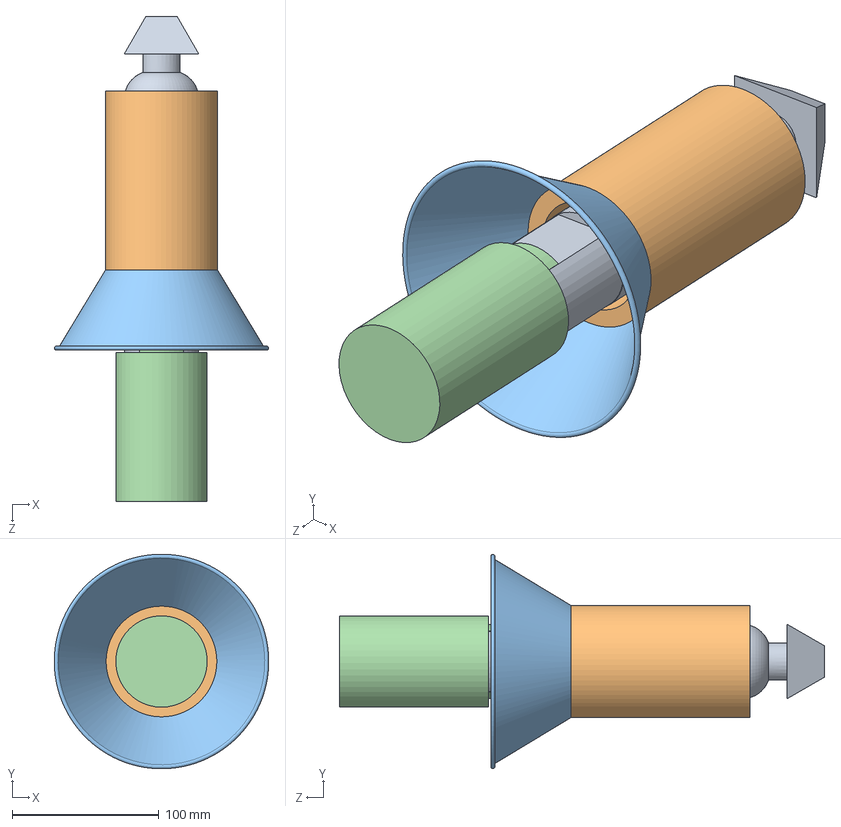
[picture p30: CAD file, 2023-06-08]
LinkedVehicles-Winter-Spring2023/CAD/Trike assembly/male and female basic.SLDASM
146.0 x 146.0 x 330.2 mm
Male Shaft (2)
9056K221_Multipurpose_6061_Aluminum_Round_Tube (1)
8996T14_24_oz._Tin_Funnel Extrude Cut

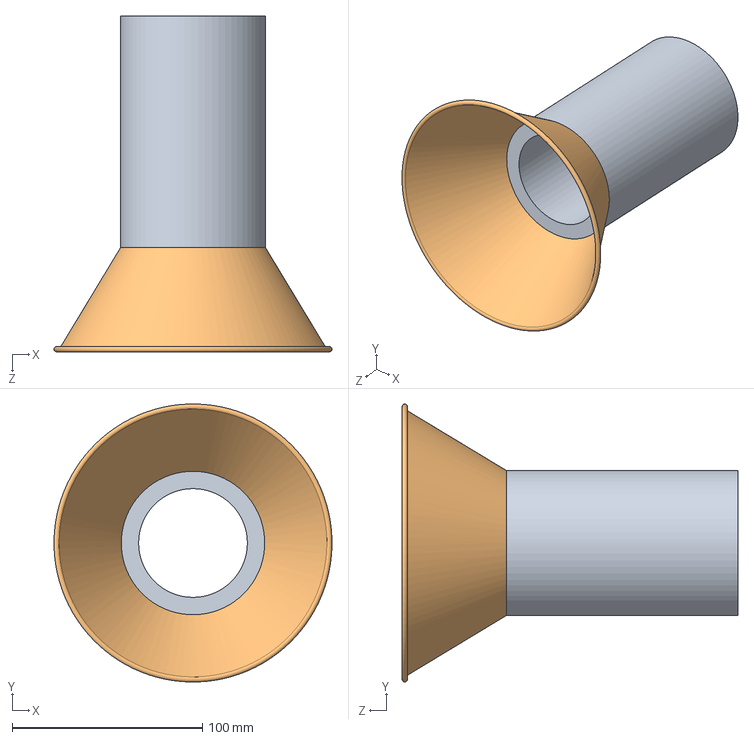
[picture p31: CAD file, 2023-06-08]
LinkedVehicles-Winter-Spring2023/CAD/male and female- v2/female revised.SLDASM
146.0 x 146.0 x 176.4 mm
9056K221_Multipurpose_6061_Aluminum_Round_Tube (1)
8996T14_24_oz._Tin_Funnel Extrude Cut

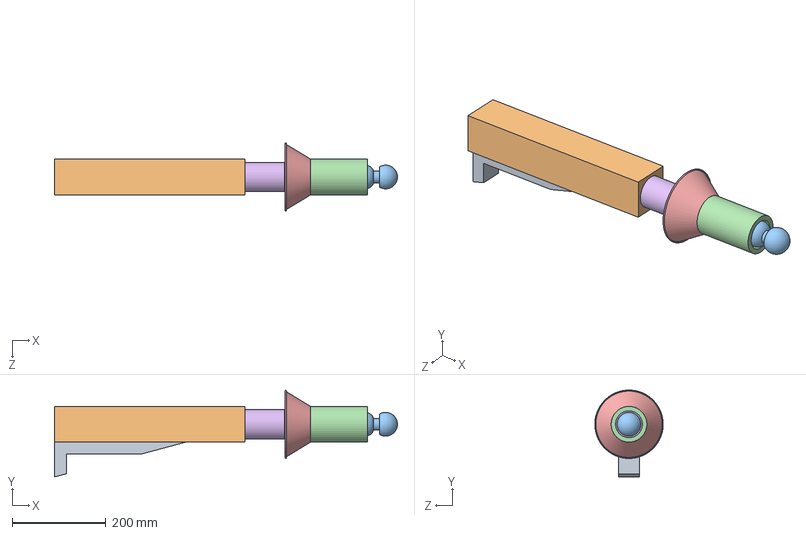
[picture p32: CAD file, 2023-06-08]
LinkedVehicles-Winter-Spring2023/CAD/Trike assembly/Front mounting ass.SLDASM
732.0 x 185.4 x 146.0 mm
Front mounting frame
Front mounting holder

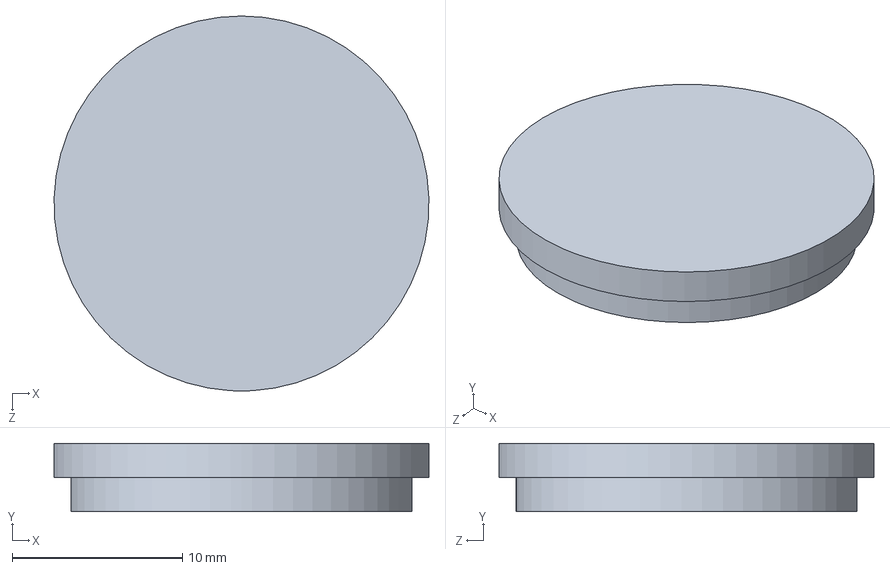
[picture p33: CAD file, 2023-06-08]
3_wire_connector_cap.SLDPRT
22.0 x 4.00 x 22.0 mm

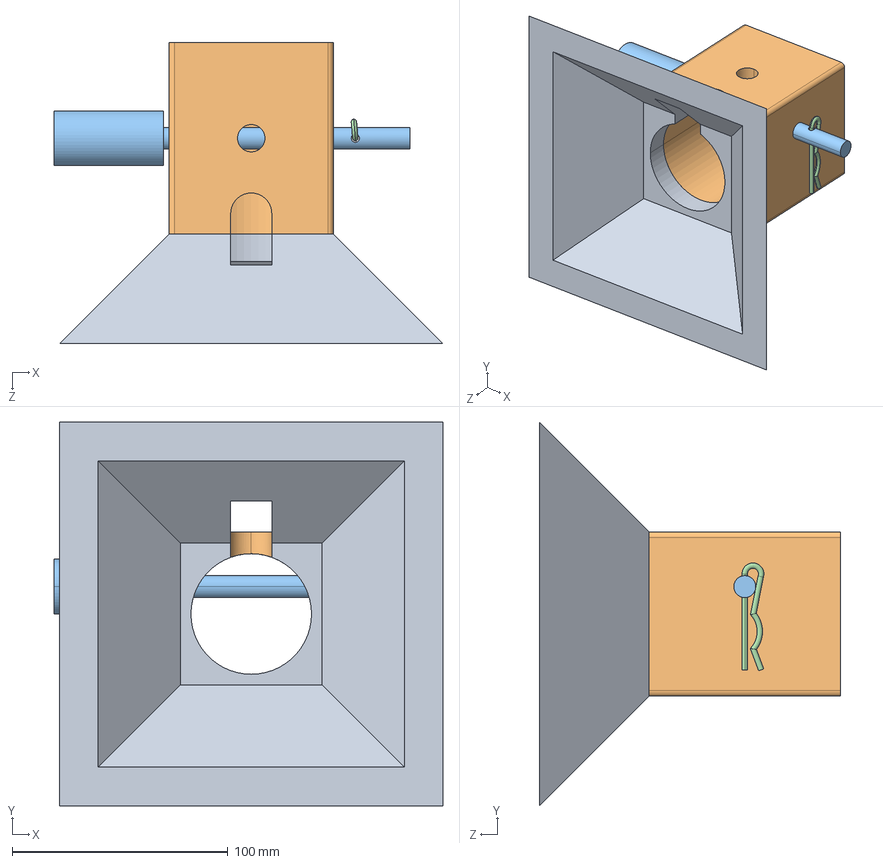
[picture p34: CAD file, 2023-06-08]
LinkedVehicles-Winter-Spring2023/CAD/Female/McHitchFemale.STEP
180.3 x 177.8 x 139.7 mm
mchitch female
mchitch pin1
rclip

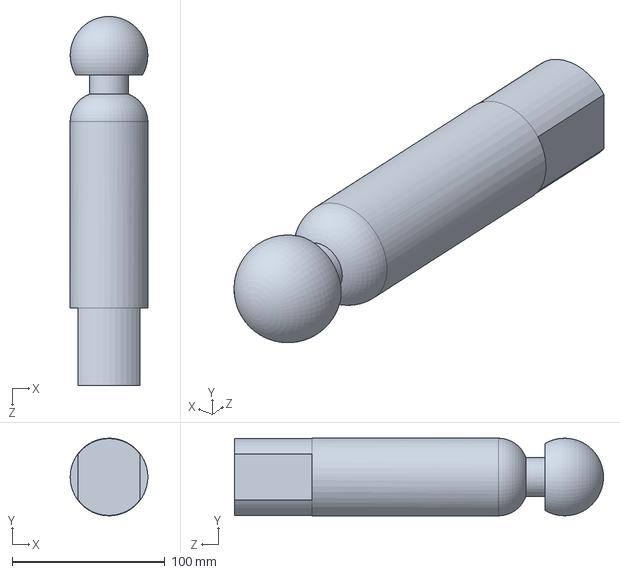
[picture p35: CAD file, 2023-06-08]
LinkedVehicles-Winter-Spring2023/CAD/Male/Male Shaft (2).SLDPRT
50.8 x 50.8 x 241.3 mm

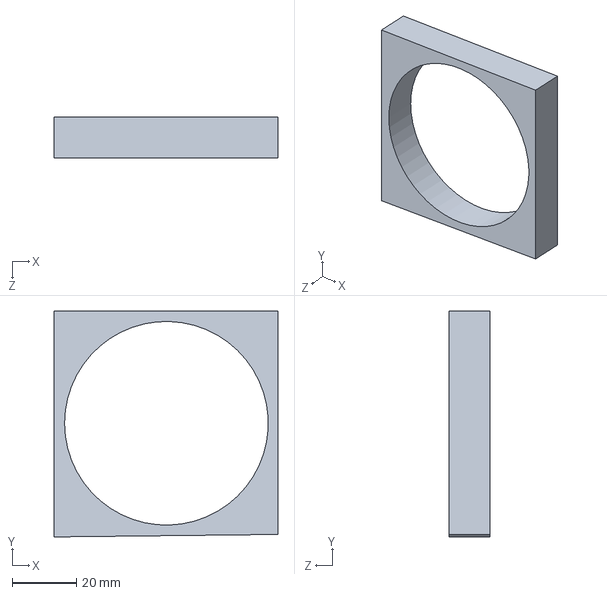
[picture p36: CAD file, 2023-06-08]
LinkedVehicles-Winter-Spring2023/CAD/New Female Part/3D printed insert.SLDPRT
69.8 x 70.4 x 12.7 mm

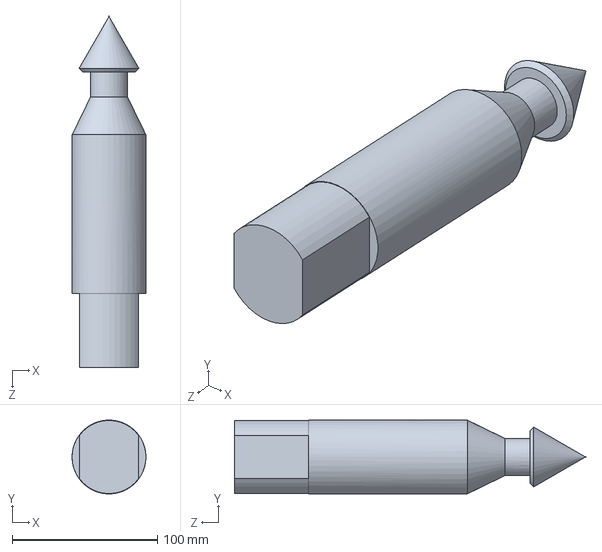
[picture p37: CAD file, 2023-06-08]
LinkedVehicles-Winter-Spring2023/CAD/Proto Lock 1.0/Male Shaft Pointed.SLDPRT
50.8 x 50.8 x 241.3 mm

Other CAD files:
LinkedVehicles-Winter-Spring2023/CAD/male and female- v2/Male Shaft Assembly LP.SLDASM
LinkedVehicles-Winter-Spring2023/CAD/male and female/female revised.SLDASM
LinkedVehicles-Winter-Spring2023/CAD/male and female- v2/male and female.SLDASM
LinkedVehicles-Winter-Spring2023/CAD/Trike assembly/female revised.SLDASM
LinkedVehicles-Winter-Spring2023/CAD/male and female/Male Shaft Assembly LP.SLDASM
3_wire_connector_top.SLDPRT
51_mm_tube_cable_mount.SLDPRT
Cable_mangment_28mm.SLDPRT
LinkedVehicles-Winter-Spring2023/CAD/Files to Turn In/Machining Drawings/Baseplate.SLDDRW
LinkedVehicles-Winter-Spring2023/CAD/Files to Turn In/Machining Drawings/Female_part.SLDDRW
LinkedVehicles-Winter-Spring2023/CAD/Files to Turn In/Machining Drawings/Lever_lock.SLDDRW
LinkedVehicles-Winter-Spring2023/CAD/Files to Turn In/Machining Drawings/Male_Shaft_Pointed.SLDDRW
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

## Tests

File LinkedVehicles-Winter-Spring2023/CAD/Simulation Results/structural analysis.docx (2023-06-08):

## Conditions:

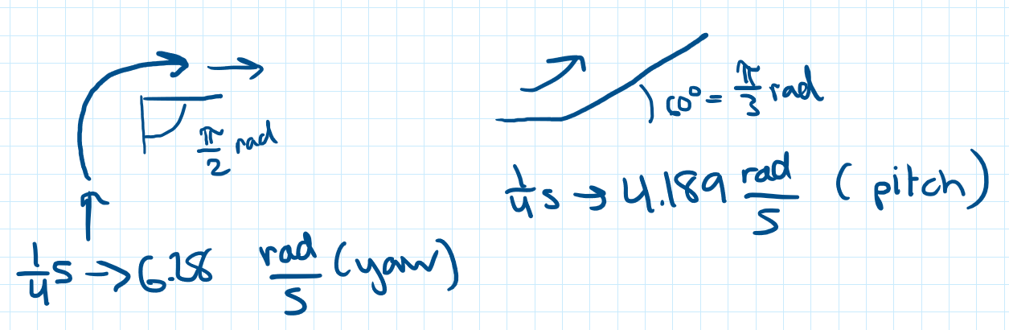
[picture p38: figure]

Angular acceleration loads. When i simulated with this i saw nothing of concern so i blasted it to 1000 lol

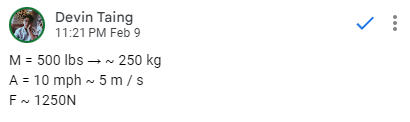
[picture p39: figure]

Base force = 1250N → with factory of safety = 4.0

Force = 5000N

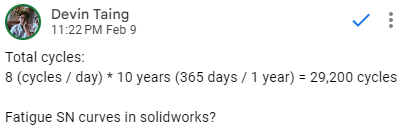
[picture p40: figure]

N cycles = 292000 → with safety factor = 2.0 → 60,000

## Funnel stuff

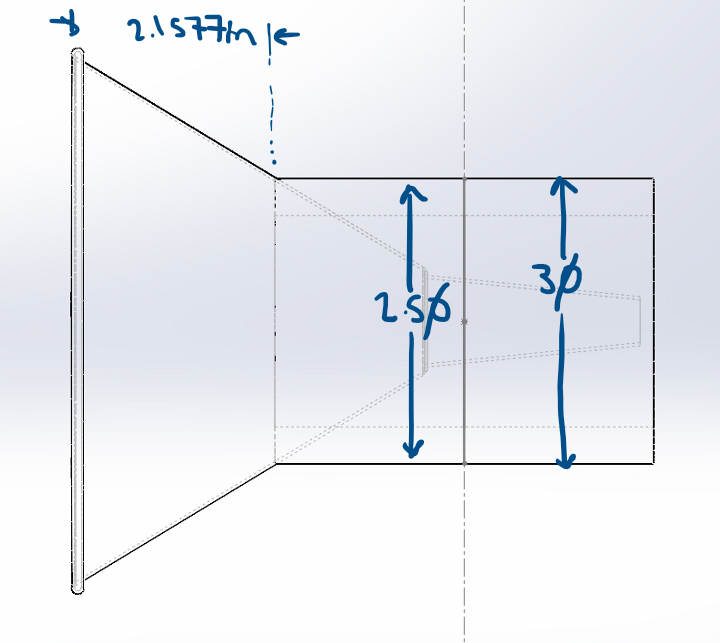
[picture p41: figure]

2.1557 in from the top, funnel diameter 3in

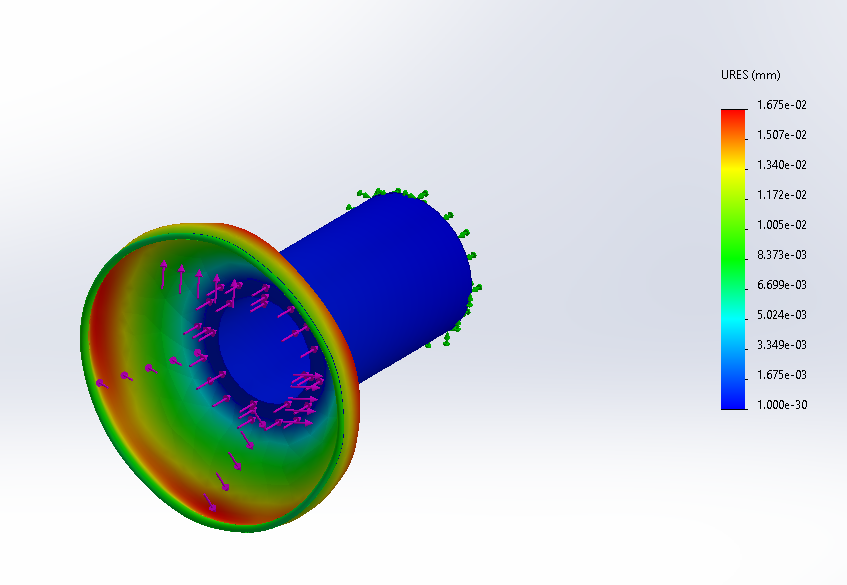
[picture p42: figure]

Simulation:

- Fixed at back end.
- Force applied to face of funnel and face of tube.
- Force applied: 1250N
- Max URES displacement: 1.675e-02 mm → 0.0659449 in
  - Located at edge of funnel
- Material: 1060 Aluminum alloy. Note: Funnel is tin, which is slightly weaker. Displacement might be higher. Reinforcement will probably be needed to survive fatigue and 29200 cycles lol

## Lever Lock

### Axial

Material for both: 1060 Alloy

Tested with a width of 0.35 inches → 0.44 pounds.

Thickness possibly could be 0.5 inches → 0.63 pounds.

For motor, test for max with 1 pound probably.

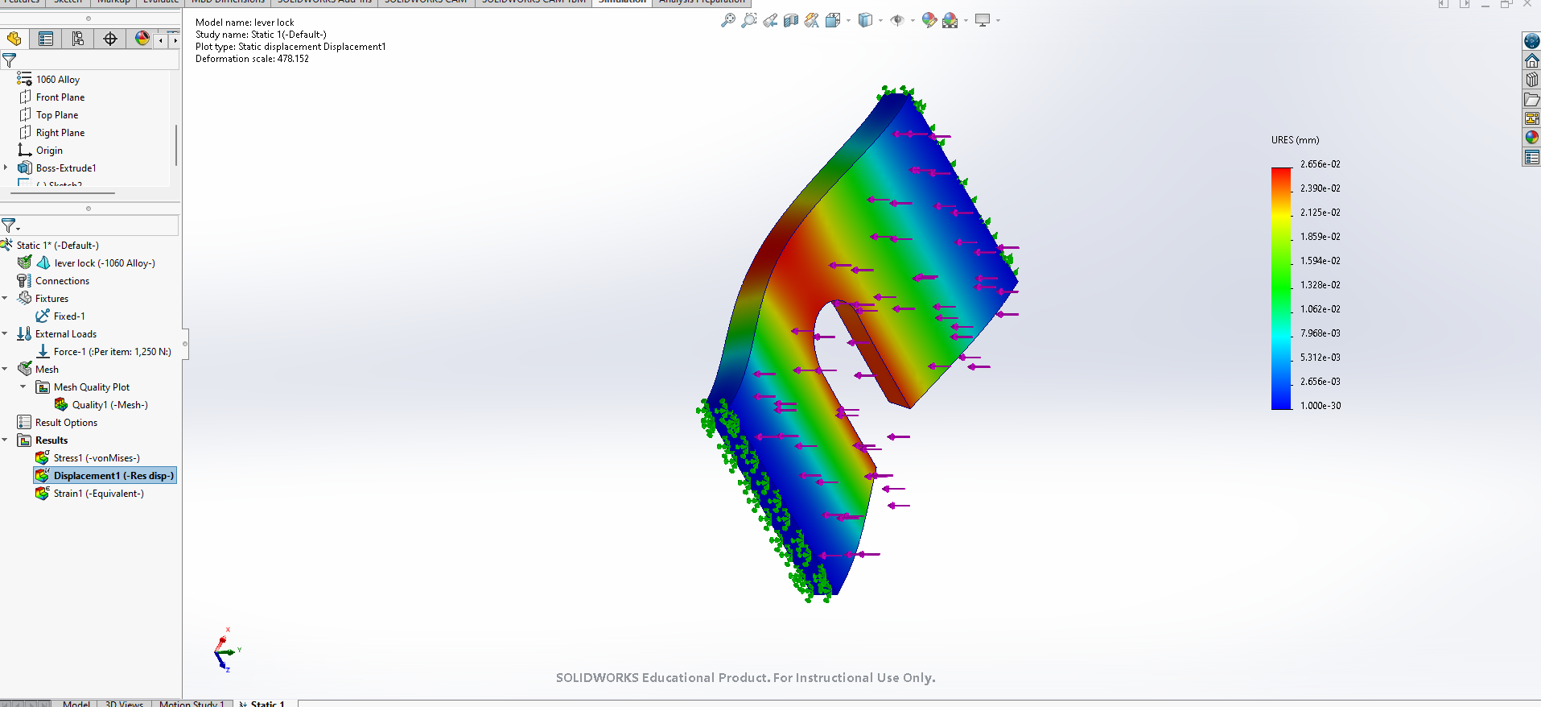
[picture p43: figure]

Sim specs:

- Fixed on both sides
- Force applied: 1250N normal to main face
  - *Force of coupling. This part should never see this much force. Wear and tear due to oscillation is the main load.
- Maximum deflection occurs in center: 2.656e-02 mm → 0.001045 in

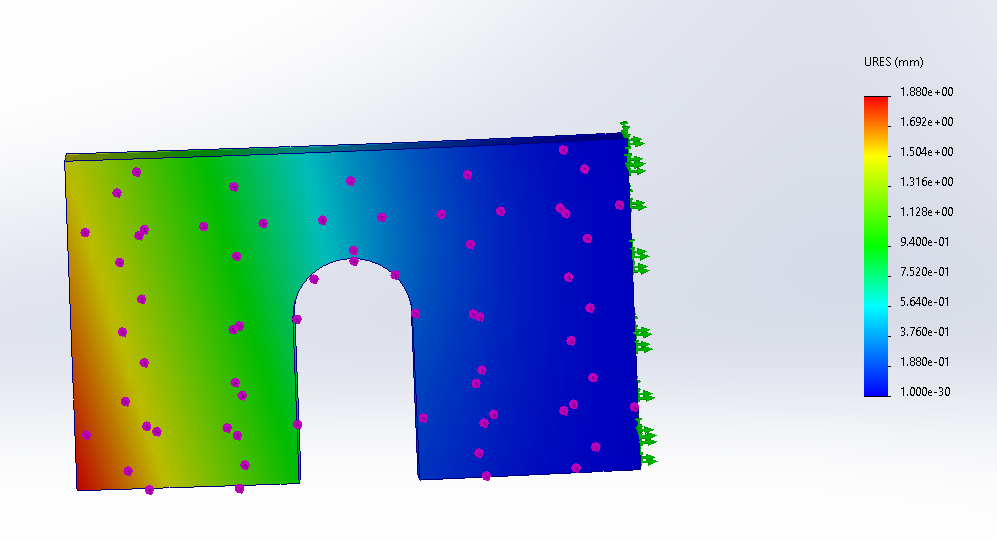
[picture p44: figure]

- Fixed on one side
- Force applied: 1250N normal to main face
- Maximum deflection occurs in center: 1.880 mm → 0.074 in
  - Bottom right edge

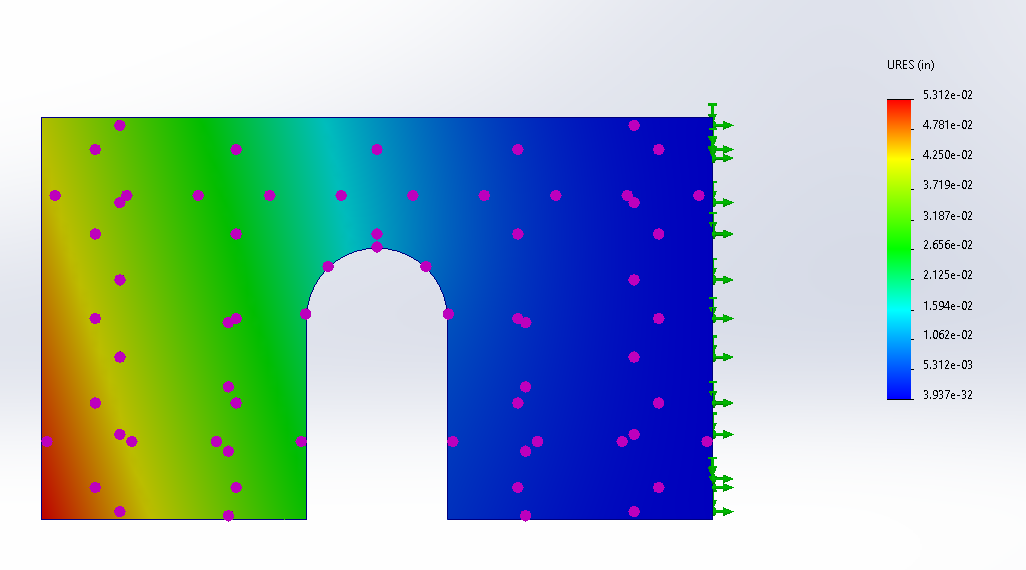
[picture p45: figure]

Force=2500N, thickness = 0.5in

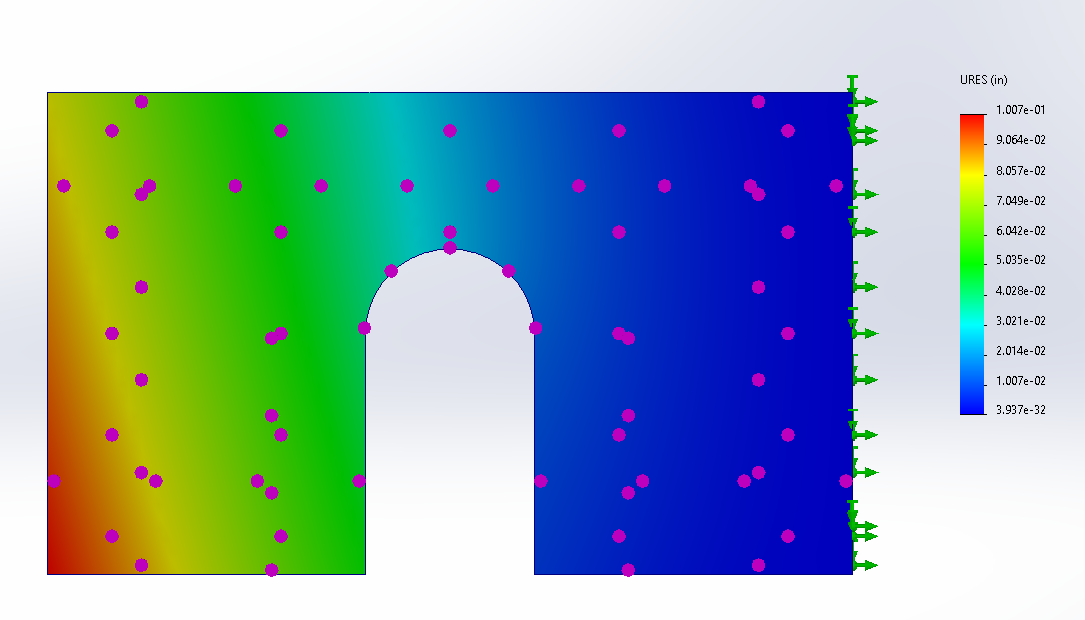
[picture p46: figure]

Force=2500N, thickness = 0.4in

### Centrifugal

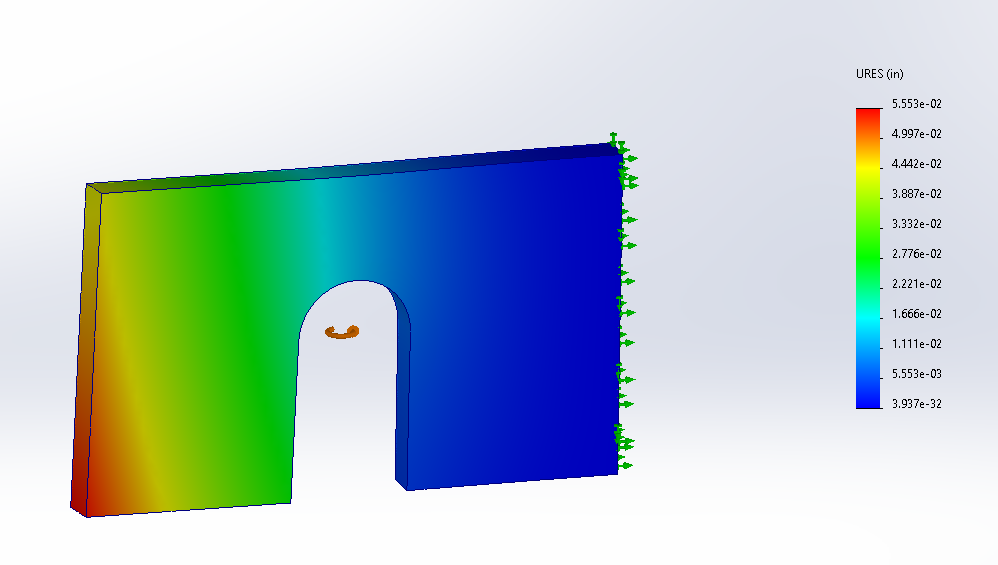
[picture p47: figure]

speed: 1000 rpm


Speed: 1000 rpm

### Fatigue Axial


N=29200, F=2500N, T=0.4in

### Fatigue Centrifugal


Lever lock still requires some more design attention. I tried to design one that would give the motor a hard time so we could have some safety factor.

## Male (lol)


Static 1: Force: 2500N


- Suppressed U-joint connect (interference caused mesh issues)
- Fixed on back
- Centrifugal force: Angular velocity = 6.28 rad/s (yaw)
- Maximum deflection occurs in center: 7.568e-08 in
  - end
- Suppressed U-joint connect (interference caused mesh issues)
- Fixed on back
- Centrifugal force: Angular velocity = 4.19 rad/s (pitch)
- Maximum deflection occurs in center: 4.454e0-8 in
  - End


- Suppressed U-joint connect (interference caused mesh issues)
- Fixed on back & indent
- Centrifugal force: Angular velocity = 6.28 rad/s (yaw)
- Maximum deflection occurs in center: 8.663e-09
  - end


Speed: 1000 rad/s


Speed: 1000 rad/s


N=29,200 with Static 1. As you can see, this thing is chilling.

## Structural

Centrifugal

Due to turning. Assumed 90 degree turn in ¼ second → ω=25.12(rad)/s

Don’t know about angular acceleration yet.


Will have to remate male connections. Interference is preventing mating and simulations will not run.

Tension

Should not have to consider tension. Assumption is that control systems between vehicles are synchronous and do not create any velocity differential.

Oscillation

Shit

How do we do this

Fatigue

Top bar is 1060, bottom bar is 2024

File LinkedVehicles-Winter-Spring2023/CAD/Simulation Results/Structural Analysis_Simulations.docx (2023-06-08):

# Coupling Mechanisms

## Conditions

Axial force:

Force sensor meter thing?

Base force = 1250N

Safety factor = 2→Force = 2500N

Safety factor = 4→Force = 5000N

Zero based

Yaw N = 6.28 rad/s → safety factor = 4 → 26 rad/s

Pitch N= 4.189 rad/s → safety factor = 4 → 17 rad/s

Material for fatigue data: gray cast iron. Solidworks doesn’t have fatigue data for 1060 aluminum. I used the weakest material I could find to be safe.

## Lever Lock

Between two thicknesses, 0.4”(0.51lb) vs 0.5” (0.63lb).


### Static Axial

*Lever lock should not ever actually see this much force. Oscillating collision is a bigger concern but this was kind of a way to gauge it.

Test | Result (T = 0.4”) | Result (T = 0.5”)


F=5000N Safety = 4


F=2500N Safety = 2

Conclusions:

- Both are passable in terms of the forces it will be subjected to.
- 0.5” thickness suffers only half the displacement compared to 0.4”. If this is machinable it will be a better choice long term.

### Static Centrifugal

Test | Result (Safety = 4, T=0.5”)


N = 17/s
N=26/s

### Fatigue Axial

Test | Result (T = 0.5”, Safety =4, F=5000N) | Result (T = 0.5”, Safety =2, F=2500N)


N=60,000

### Fatigue Centrifugal - Incomplete

Test | Result (T = 0.5”, Safety =4)


Both pitch and yaw
F=2500N Safety = 2

## Funnel

### Static Axial

Test | Result


F=5000N Safety = 4


F=2500N Safety = 2

### Static Centrifugal

Test | Result


Pitch N=17/s
Yaw N=26/s

### Fatigue Axial

Test | Result


N=60,000 F=5000N

### Fatigue Centrifugal - Incomplete

## Male

### Static Axial

Test | Result


F=5000N
F=2500N

### Static Centrifugal

Test | Result


Yaw N=26/s


Pitch N=17/s

### Fatigue Axial

Test | Result


N=60000 F=5000N
N=60000 F=2500N

### Fatigue Centrifugal - Incomplete

# Mounting

## Conditions

Weight of coupling system: 10 kg

10 kg * 10 m/(s^2) =100N

Current total mounting length: 24” (arbitrarily chosen) → 0.61m

Overhang length = 12.96” → 0.33m.


## Screenshots


Front end support frame
Front end support frame


Front end support frame + mounting


Front end support frame + mounting


Front end support frame + mounting + coupling mechanism


Front end support frame + mounting + coupling mechanism + trike


Front end support frame + mounting + coupling mechanism + 2 trikes

What I need:

- U-joint dimensions
- Better pictures of the trikes
- Trike dimensions

Design drivers:

- Distance between vehicles
- Weight (can bike rack support?)
- How to fabricate?

Strain gauge?

P=VI=Fv

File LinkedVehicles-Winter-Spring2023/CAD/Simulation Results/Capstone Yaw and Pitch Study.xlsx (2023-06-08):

Static Test results at 1250 N
Pitch (degrees) | Stress (MPa) | Displacement (mm) | Strain | Yaw (degrees) | Stress (MPa) | Displacement (mm) | Strain
0 | 3.037 | 0.005517 | 2.31 E-05 | 0 | 3.037 | 0.005517 | 2.31 E-05
5 |  |  |  | 10
10 |  |  |  | 20
15 | 20.07 | 0.3998 | 1.605 E-04 | 30 | 94.66 | 0.7771 | 7.29 E-04
